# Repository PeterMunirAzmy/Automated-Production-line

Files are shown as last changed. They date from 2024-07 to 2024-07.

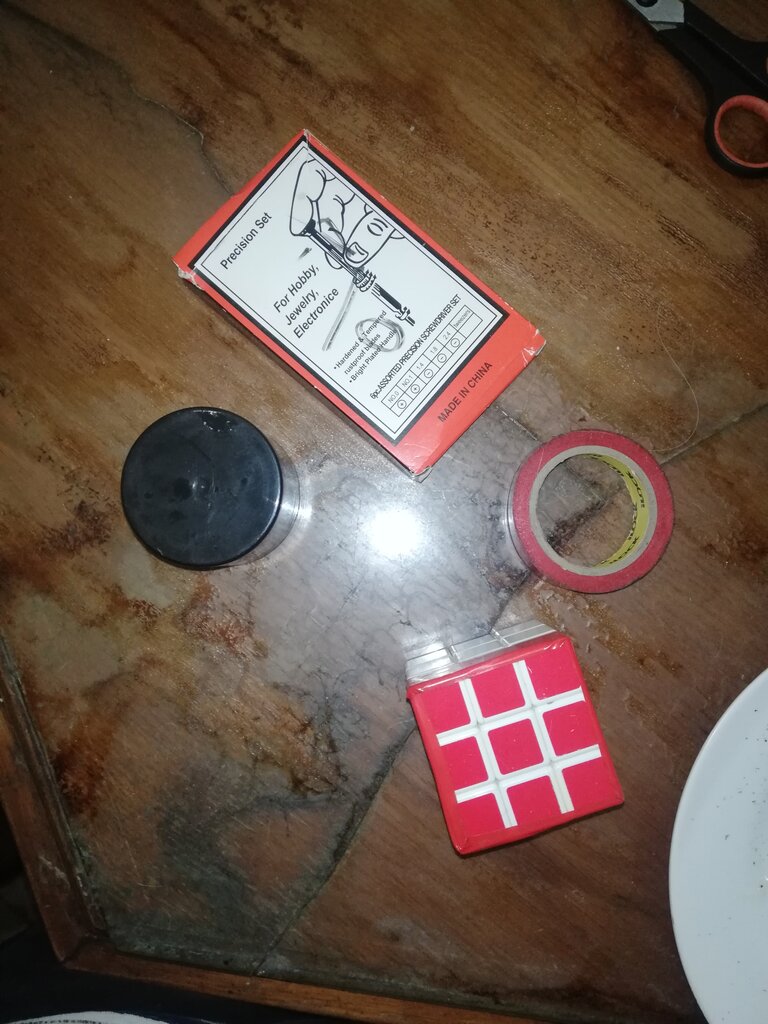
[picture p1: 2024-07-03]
Mechatronics System Desigen/Code/pythonProject/TestImg/objects6 (1).jpg

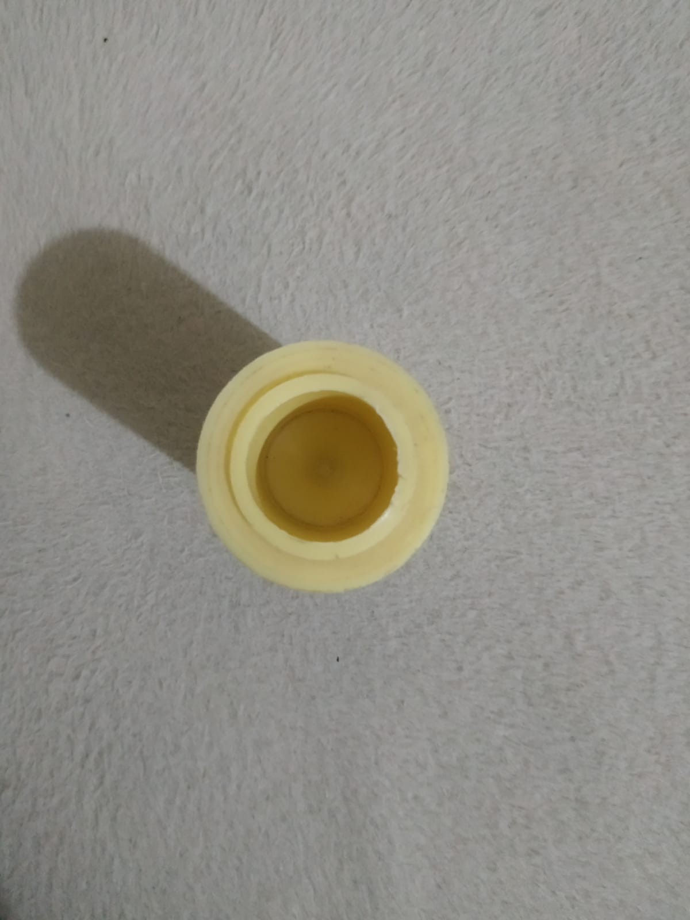
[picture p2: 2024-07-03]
Mechatronics System Desigen/Code/pythonProject/TestImg/circlepeter.jpg

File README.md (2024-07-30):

<h1>Automated Production Line Using Robot Arm</h1>
    <p>This repository contains the files and documentation for a comprehensive automated production line system designed and implemented using a combination of wood, 3D printed parts, NEMA 17 stepper motors, a DC motor, PID control, and CNC V3 shield. The system includes feeding, sorting, handling, assembly, and storage stages, with a vision system for sorting and precise control of a robot arm.</p>

<h2>Table of Contents</h2>
    <ul>
        <li><a href="#overview">Overview</a></li>
        <li><a href="#features">Features</a></li>
        <li><a href="#design-and-fabrication">Design and Fabrication</a></li>
        <li><a href="#control-system">Control System</a></li>
        <li><a href="#vision-system">Vision System</a></li>
        <li><a href="#simulations">Simulations</a></li>
        <li><a href="#hardware-components">Hardware Components</a></li>
        <li><a href="#software">Software</a></li>
        <li><a href="#installation">Installation</a></li>
        <li><a href="#contributing">Contributing</a></li>
    </ul>

<h2 id="overview">Overview</h2>
    <p>The project aims to automate a production line using a robot arm. The system handles multiple stages, including feeding, sorting, handling, assembly, and storage. The design leverages both mechanical and electronic components to ensure precision and reliability.</p>

<h2 id="features">Features</h2>
    <ul>
        <li><strong>Comprehensive Production Line:</strong> Includes stages for feeding, sorting, handling, assembly, and storage.</li>
        <li><strong>Precision Control:</strong> Utilizes NEMA 17 stepper motors and a DC motor with PID control for accurate movement.</li>
        <li><strong>Vision System:</strong> Developed for sorting tasks, ensuring items are correctly categorized.</li>
        <li><strong>Simulations:</strong> MATLAB Simulink used for kinematics and trajectory planning.</li>
        <li><strong>Arduino Control:</strong> Arduino Uno programmed for precise control of the robot arm.</li>
        <li><strong>Modular Design:</strong> Components designed for easy fabrication and assembly.</li>
    </ul>

<h2 id="design-and-fabrication">Design and Fabrication</h2>
    <ul>
        <li><strong>Structural Components:</strong> Fabricated from 4mm thick wood sheets for durability and ease of construction.</li>
        <li><strong>Robot Arm:</strong> 3D printed for precision and durability.</li>
        <li><strong>Software Used:</strong> Autodesk Inventor for design and modeling.</li>
    </ul>

<h2 id="control-system">Control System</h2>
    <ul>
        <li><strong>Motors:</strong> NEMA 17 stepper motors and a DC motor.</li>
        <li><strong>Control:</strong> PID control implemented for precision.</li>
        <li><strong>Coordination:</strong> CNC V3 shield used for seamless motor coordination.</li>
    </ul>

<h2 id="vision-system">Vision System</h2>
    <ul>
        <li><strong>Development:</strong> Custom vision system for sorting items on the production line.</li>
        <li><strong>Integration:</strong> Vision system integrated with the control system for automated sorting.</li>
    </ul>

<h2 id="simulations">Simulations</h2>
    <ul>
        <li><strong>MATLAB Simulink:</strong> Used for simulating kinematics and trajectory planning.</li>
    </ul>

<h2 id="hardware-components">Hardware Components</h2>
    <ul>
        <li><strong>Motors:</strong> NEMA 17 stepper motors, DC motor.</li>
        <li><strong>Microcontroller:</strong> Arduino Uno.</li>
        <li><strong>Shield:</strong> CNC V3 shield.</li>
        <li><strong>Structural:</strong> 4mm thick wood sheets, 3D printed parts.</li>
    </ul>

<h2 id="software">Software</h2>
    <ul>
        <li><strong>Arduino IDE:</strong> For programming the Arduino Uno.</li>
        <li><strong>MATLAB Simulink:</strong> For simulations.</li>
        <li><strong>Autodesk Inventor:</strong> For design and modeling.</li>
    </ul>

<h2 id="installation">Installation</h2>
    <ol>
        <li>Clone the repository:
            <pre><code>git clone https://github.com/yourusername/automated-production-line.git
cd automated-production-line</code></pre>
        </li>
        <li>Install the necessary software:
            <ul>
                <li>MATLAB Simulink</li>
                <li>Autodesk Inventor</li>
                <li>PyCharm</li>
                <li>Arduino IDE</li>
            </ul>
        </li>
        <li>Assemble the hardware components as per the design files provided.</li>
        <li>Upload the Arduino code to the Arduino Uno using the Arduino IDE.</li>
    </ol>

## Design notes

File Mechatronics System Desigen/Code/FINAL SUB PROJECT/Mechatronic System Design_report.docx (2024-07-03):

AIN SHAMS UNIVERSITY

FACULTY OF ENGINEERING

# Mechatronics Engineering

MCT 333s

MS UNIVERSITY

FACULTY OF ENGINEERING

# Mechanical Power Engineering

# MEP221s

MS UNIVERSITY

FACULTY OF ENGINEERING

# Mechanical Power Engineering

# MEP221s

MS UNIVERSITY

FACULTY OF ENGINEERING

# Mechanical Power Engineering

# MEP221s

MS UNIVERSITY

FACULTY OF ENGINEERING

# Mechanical Power Engineering

# MEP221s

MS UNIVERSITY

FACULTY OF ENGINEERING

# Mechanical Power Engineering

# MEP221s

MS UNIVERSITY

FACULTY OF ENGINEERING

# Mechanical Power Engineering

# MEP221s

MS UNIVERSITY

FACULTY OF ENGINEERING

# Mechanical Power Engineering

# MEP221s

MS UNIVERSITY

FACULTY OF ENGINEERING

# Mechatronics Engineering

# MEP221s

MS UNIVERSITY

FACULTY OF ENGINEERING

# Mechanical Power Engineering

# MEP221s

MS UNIVERSITY

FACULTY OF ENGINEERING

# Mechanical Power Engineering

# MEP221s

MS UNIVERSITY

FACULTY OF ENGINEERING

# Mechanical Power Engineering

# MEP221s

MS UNIVERSITY

FACULTY OF ENGINEERING

# Mechanical Power Engineering

# MEP221s

MS UNIVERSITY

FACULTY OF ENGINEERING

# Mechanical Power Engineering

# MEP221s

MS UNIVERSITY

FACULTY OF ENGINEERING

# Mechanical Power Engineering

# MEP221s

MS UNIVERSITY

FACULTY OF ENGINEERING

# Mechanical Power Engineering

# MEP221s

Mechatronic System Design

(MCT 333s)

Production line project

NAME LIST:

Team (20)

NO | B. N | NAME | ID | sec
1 | | Peter Munir Azmy | 1901934 | 2
2 | | Fares Ahmed Mohamed | 19P6135 | 2
3 | | Hassan Ahmed Mohamden | 2002008 | 2
4 | | Ahmed Hawary Abdelrehem ali | 2000135 | 2
5 | | Mahmoud Mohamed Ibrahim Ali | 2001481 | 3
6 | | Mohamed Hany Farouk | 2001266 | 3

- Introduction:

A production line, also known as an assembly line, is a manufacturing process in which parts are added to a product in a sequential manner to create a finished product more efficiently. This method is used in mass production and involves a series of workstations that perform different tasks simultaneously, but at a controlled pace. The key advantages of a production line include increased productivity, more efficient use of materials, improved product quality, and faster production times. This system was popularized by Henry Ford in the early 20th century, revolutionizing the automotive industry by making the assembly process quicker and more cost-effective. Today, production lines are integral to various industries, including electronics, food, and pharmaceuticals, adapting to new technologies such as automation and robotics to enhance efficiency and precision.

- machine vision with production line _robotic arm:

A robotic arm with machine vision on a production line represents the pinnacle of technological integration in industrial automation, blending precision mechanics with sophisticated image processing capabilities. These robotic arms are equipped with cameras and sensors that allow them to "see" their environment. This ability to visually analyze their surroundings enables them to perform complex tasks such as quality control inspections, precise assembly, and intricate component handling with higher accuracy and adaptability.

Machine vision systems enable robotic arms to identify, sort, and position parts with a level of precision that far surpasses human capabilities. These systems use real-time data to guide the robot's actions, allowing for adjustments on the fly and enabling the handling of a diverse range of products without manual reprogramming. This integration significantly enhances the flexibility and efficiency of production lines, particularly in industries where customization and high-quality standards are critical, such as in electronics manufacturing, pharmaceuticals, and automotive assembly.

The use of machine vision in robotic arms not only boosts production throughput and product quality but also reduces waste and operational costs by minimizing errors and improving safety. As part of smart manufacturing practices, these technologically advanced robotic systems play a crucial role in the ongoing evolution of Industry 4.0, pushing the boundaries of what automated production lines can achieve.

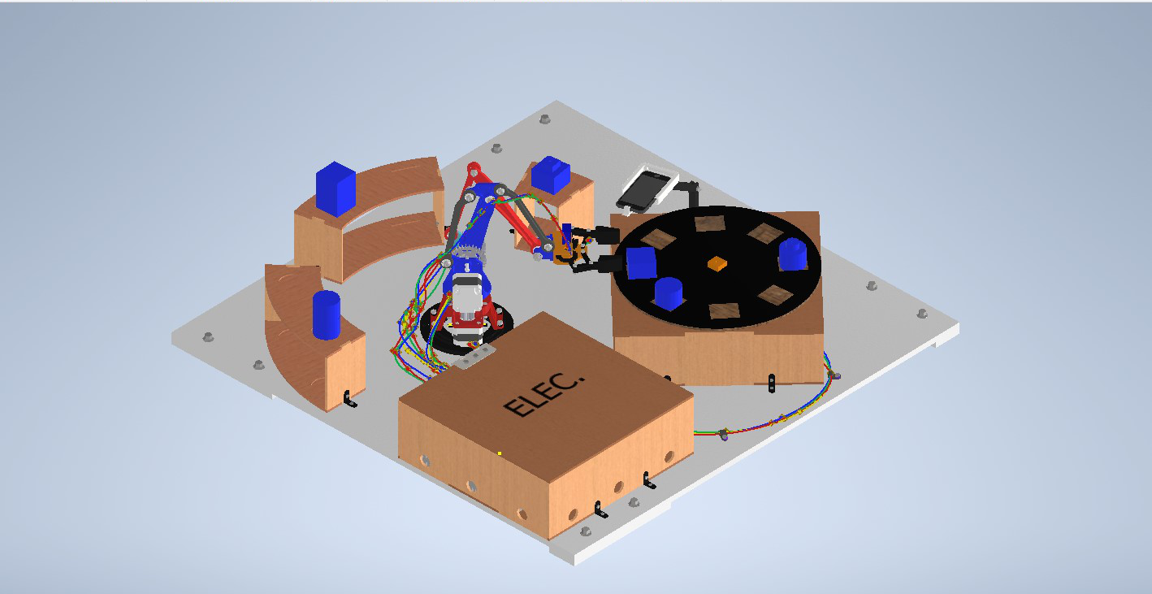
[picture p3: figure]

Machine vision camera

Square surface detection

- V_model techniques for project:

In this project, we are constrained by 5 main stages, but we can make any design to achieve these stages, we design a simple design with main robot arm to make most of it.

- We select our requirements based on 5 stages:

Stage | Function | Requirement
1-Feeding | Feeding the products to certain position to pick up by the robot | We make a feeding mechanism by rotating disk rotated by DC motor controlled by PID controller
2-Sorting | Sorting the products based on shapes (circle _square) by edge detection | we need to use machine vision (via camera)
3-handling | we need to handle the products from place to place and assembly the similar products which other and storge it | We need to a robotic arm can make this function with 3 DOF or more with end effector
4-assembly
5-storg

- Mechanical design and modeling:

We divided the production line that makes five stages for a product to 2 stations:

1- Station includes (Feeding _ sorting)
2- Station includes (handling _assembly _storage)
- Station includes (Feeding _ sorting):
- Mechanical design:

The design of the feeding mechanism depends on the presence of a disk that rotates with the help of a DC motor with a PID controller to adjust the circular angles divided into every 45 degrees (in the form of square shape ), from which the robot picks up the product after classifying it with the camera that knows if the type of product is Where if it is circular or square in shape.

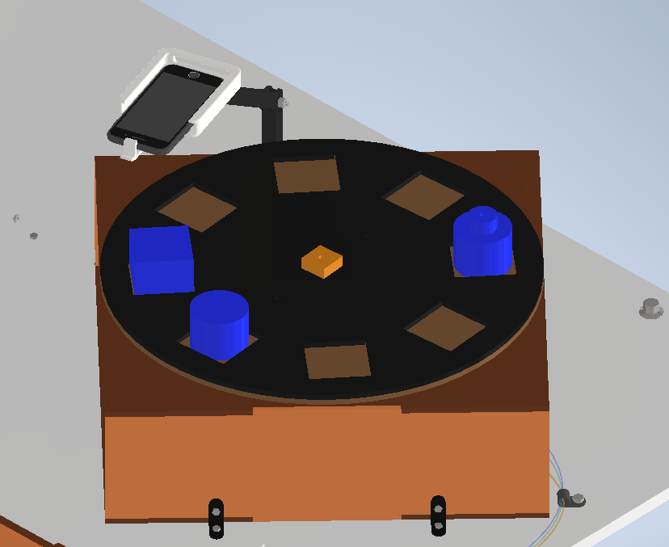
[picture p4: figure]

Image from cad file for feeding and sorting.

The used motor for feeding mechanism:

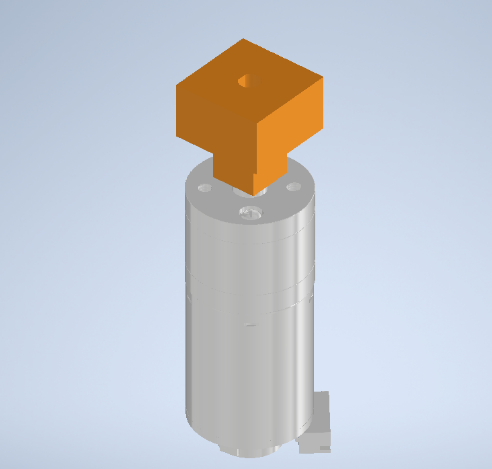
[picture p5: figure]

DC Motors 25GA-370 Metal Gear DC 12V Reduction Motor with Encoder and Gearbox for 280RPM With use with motor a 3d coupler to link between motor and rotating disk.

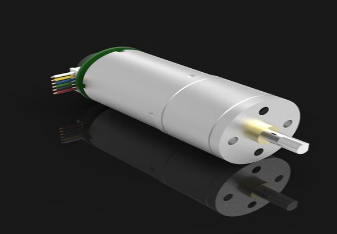
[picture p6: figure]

Dc motor

3D printed coupler

dc motor with coupler

The used camera is:

We use a mobile camera (mi note 10) connected with laptop by program (Iriun Webcam) with stand from our design to hold it.

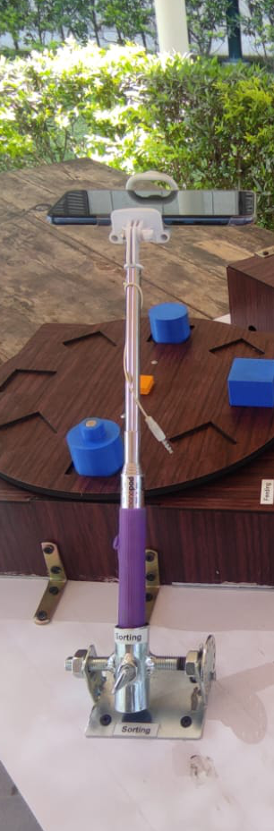
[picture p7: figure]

We use a thrust bearing (51105) between the rotating disk and the fixed surface to reduce the friction force.

- Modeling and simulation:

by using MATLAB Simulink to model the system

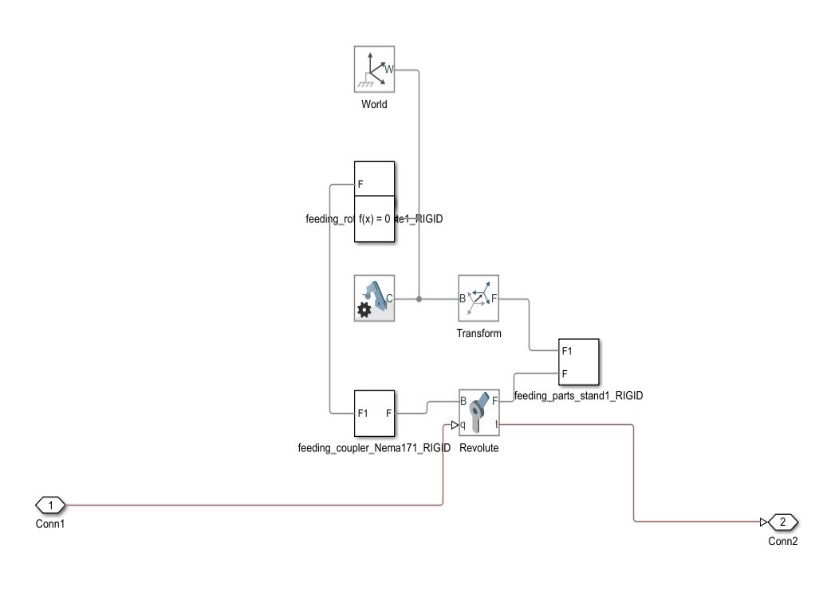
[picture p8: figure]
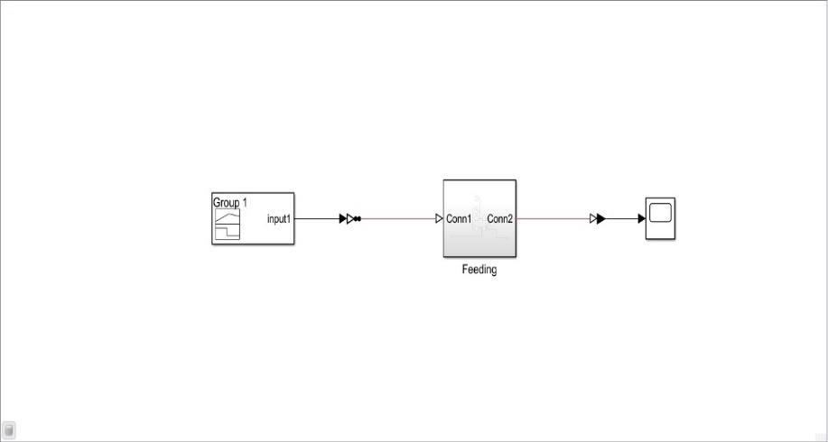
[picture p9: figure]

Feeding model in MATLAB

From the results we select the motor which achieves this torque and actuate the mechanism and the is DC Motors 25GA-370 Metal Gear DC 12V Reduction Motor with Encoder and Gearbox for 280RPM with Stall Torque: 3Kg/cm.

Link of cad files:

- Station includes (handling _assembly _storage):
- Mechanical design:

In these 3 stages, the robot picks up the product, then assembles it with a similar part, then storges it in a desired place for that.

This 3DOF_ robot is made by Florin Tobler _2016 and we make an inverse engineering to it to be suitable at this case and can matching with Egyptian industry conditions and the presence of components in the markets.

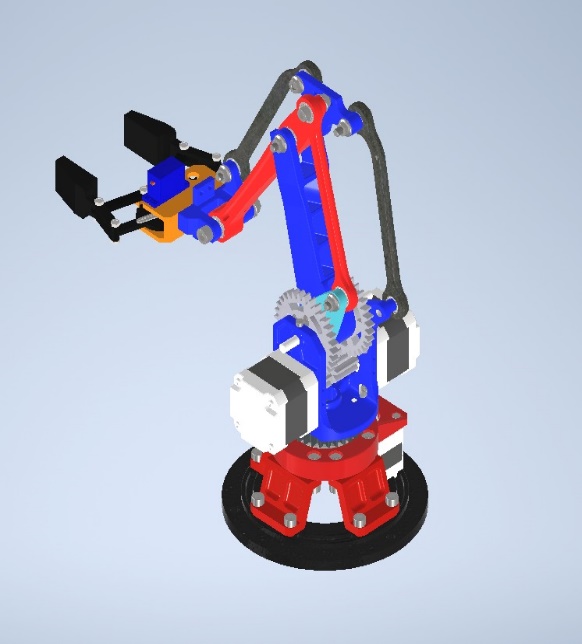
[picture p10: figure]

Robotic arm from cad file

For the robotic arm we use inverse engineering techniques to check everything at the robot:

1- length of links and its ability to achieve the function.
2- considering the friction between joints by using a lot of types from bearing (deep grove ball bearing (686zz) – thrust bearing (51105)).

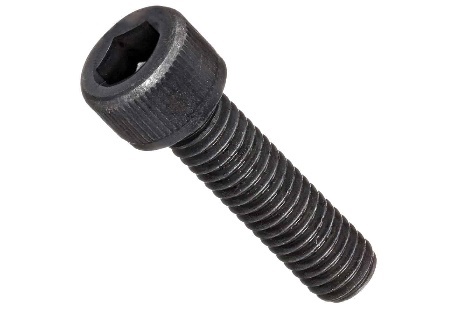
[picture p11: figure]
Socket Head Cap Screws - Metric - DIN 912 | TFC Ltd
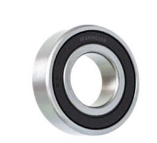
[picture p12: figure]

3- the loads in each part and the selection motor by modeling it MATLAB.
4- Considering The techniques of fabrication on The Egyptian environment and Availability of screws, nuts, and fixing tools.

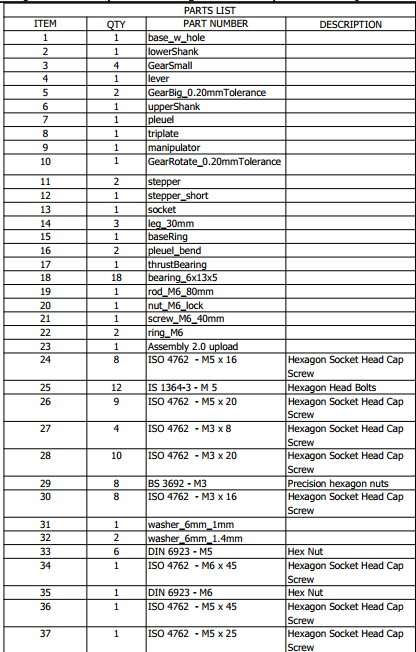
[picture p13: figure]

the BOM to robot arm:

5- Considering The size and the loads of the gripper and an ability to hold the parts.
- Modeling and simulation:

by using MATLAB Simulink to model the system

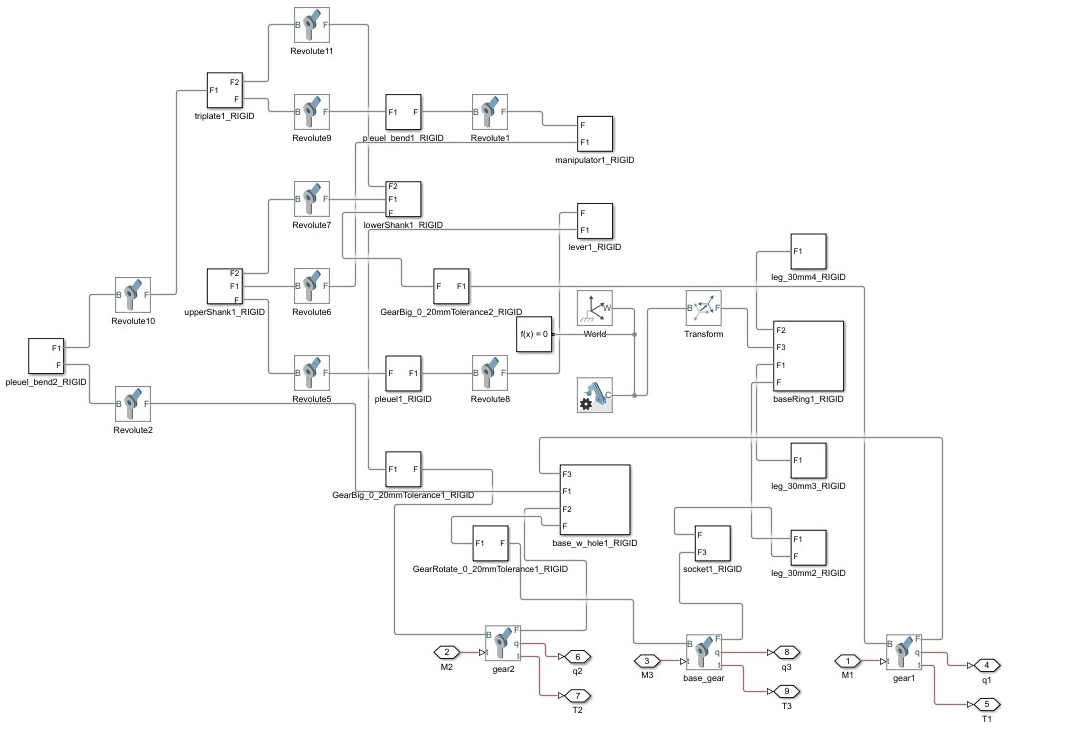
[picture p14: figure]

Cad file robot in Simulink

-Actuator sizing:

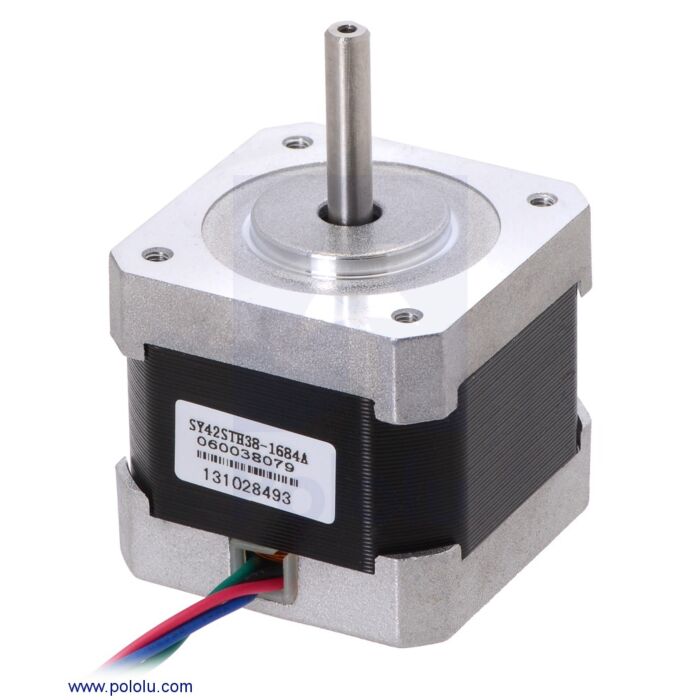
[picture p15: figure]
Stepper Motor: Bipolar, 200 Steps/Rev, 42×38mm, 2.8V, 1.7 A/Phase | POLOLU-2267 | Core Electronics Australia

From the results we select the motor which achieves this torque and actuate the mechanism and the is This robot will be actuator by stepper motor _Nema 17_to achieving arrival for certain angle.

We use 3 motors to actuate 3 angles in a robot arm.

-Inverse kinematics:

Inverse kinematics allows precise control over the motion of the end effector by calculating the required joint configurations to achieve a desired position and orientation in the workspace.

For robotic arms with multiple joints, determining the joint angles manually to reach a specific end effector position.

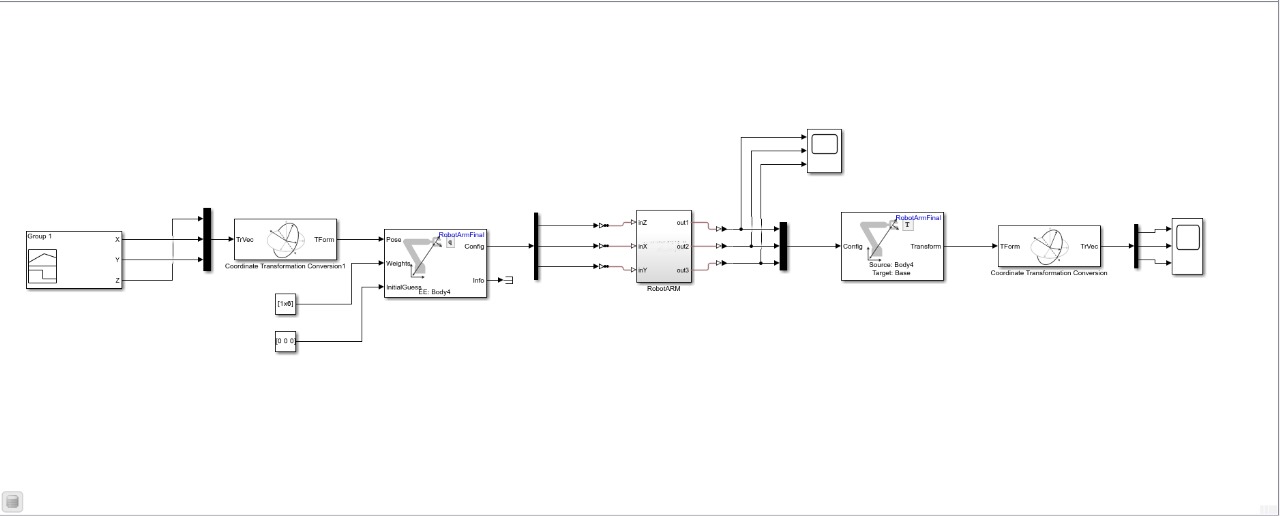
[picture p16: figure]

-Forward kinematics:

in robot kinematics, forward kinematics refers to the use of the kinematic equations of a robot to compute the position of the end-effector from specified values for the joint parameters.

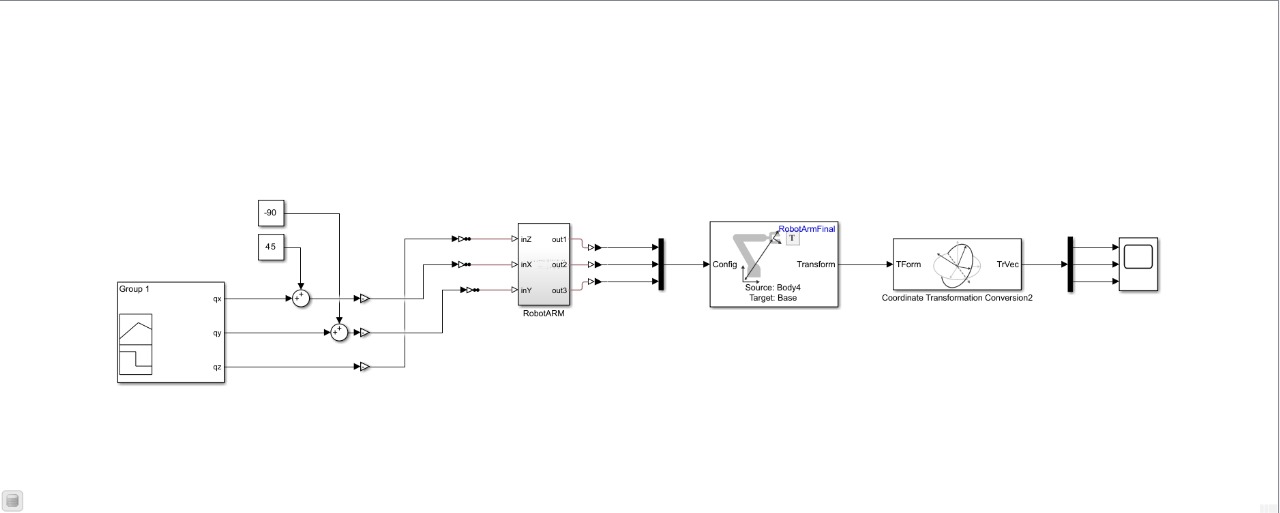
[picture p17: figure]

- trajectory planning:

robot manipulator trajectory planning takes the ideal trajectory kinematics parameters and the robot manipulator system as the input, and takes the displacement, velocity and acceleration of each joint and end effector as the output.

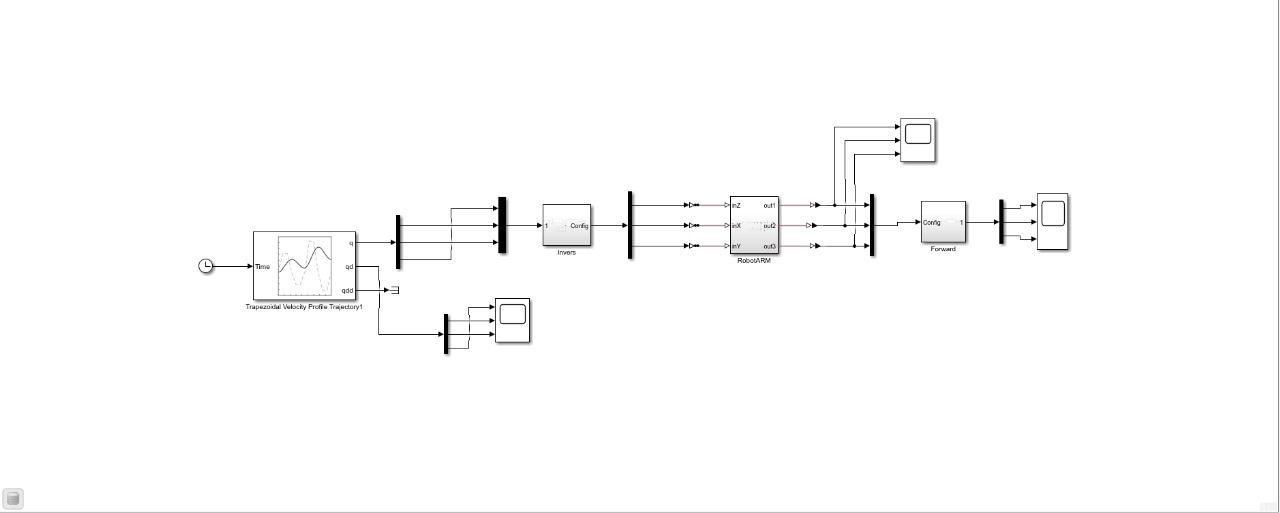
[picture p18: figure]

-Jacobian matrix:

Jacobian is the determinant of the Jacobian matrix. The matrix will contain all partial derivatives of a vector function. The main use of Jacobian is found in the transformation of coordinates. It deals with the concept of differentiation with coordinate transformation.

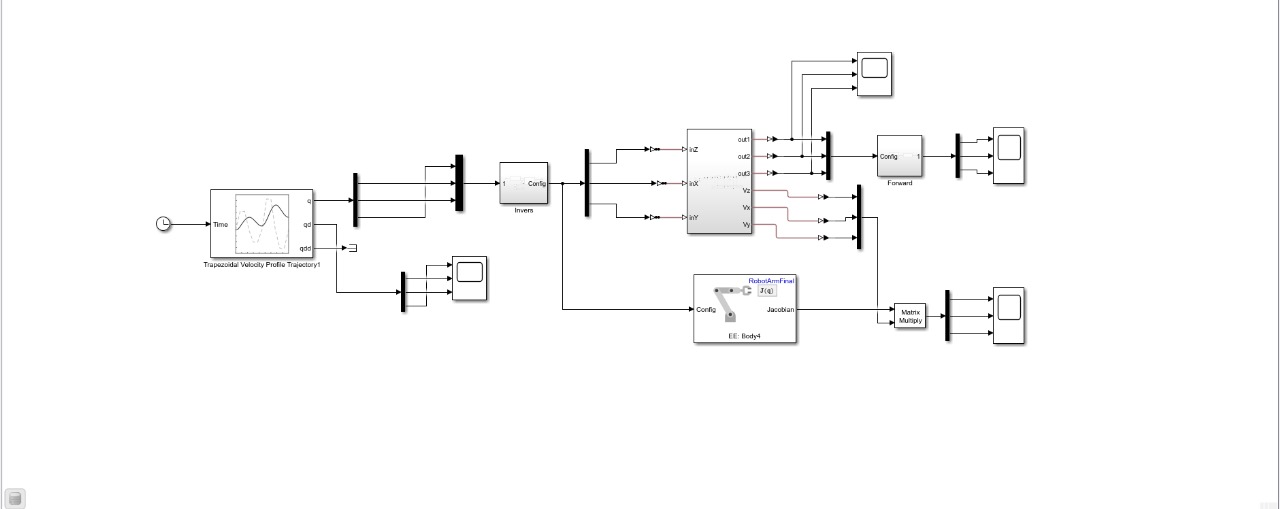
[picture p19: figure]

- The fabrication processes:

We use wooden laser cut to build the feeding mechanism and the stand which the robot will put the products in it.

And use the 3d printer to abdicate the robot arm.

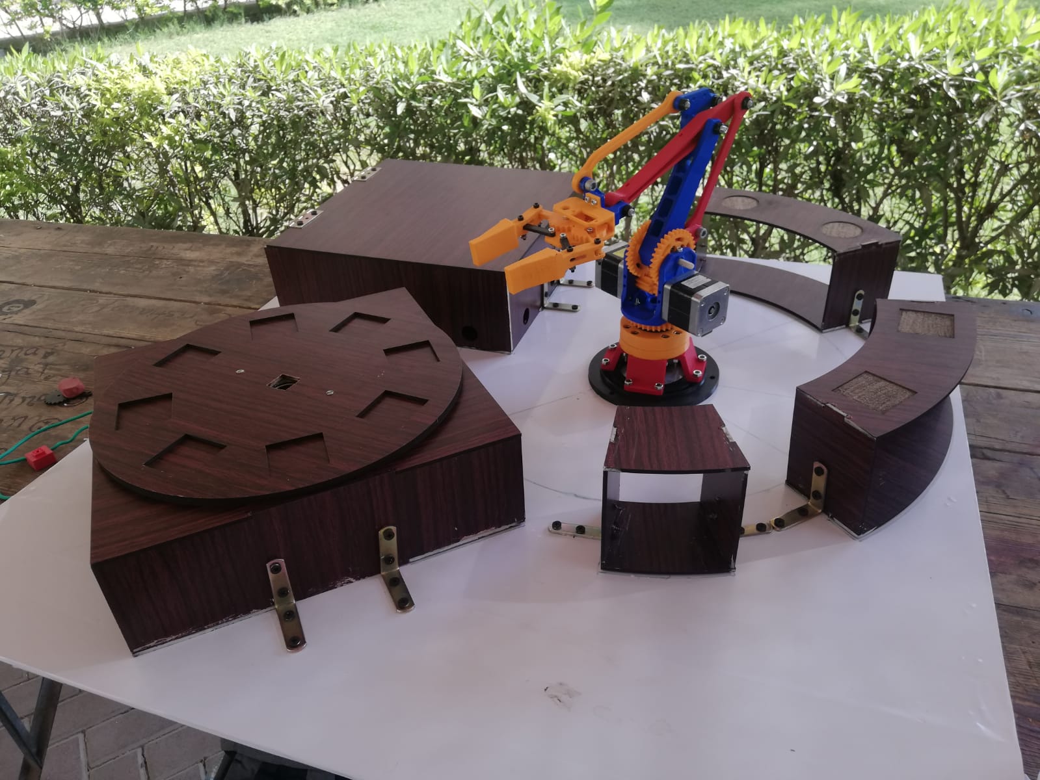
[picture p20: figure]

- The electrical system and integration:
- The sequence of the project and algorithms

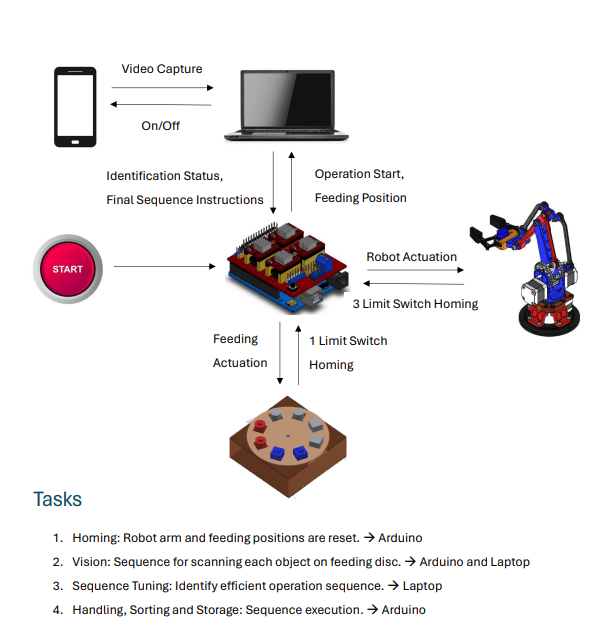
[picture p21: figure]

- Summary:

As soon as we connect the power, the robot performs a homing and returns to the initial position. After that, the feeding mechanism performs a homing and returns to the initial position. After that, the laptop takes pictures of each part separately to move to the next time once the products are captured correctly and the word “Done” is displayed, then after. The laptop then gives a sequence of the location of each product, so the robot collects similar products on this basis, assembles them, and then transports them to their storage location.

We use two microprocessors (Arduino uno - laptop) , the two microprocessors connecting with to each other with UART protocol via USB.

- Flow chart:

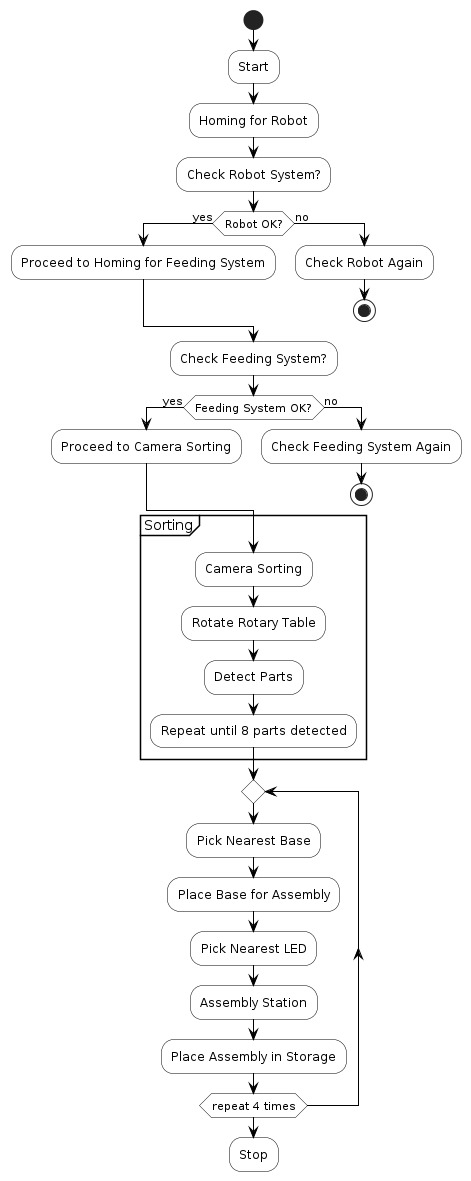
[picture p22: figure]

- the schematic electrical circuit:

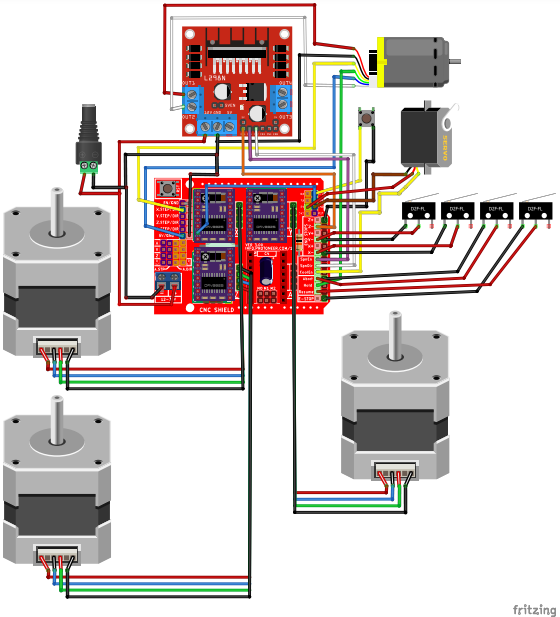
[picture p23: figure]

- The PID controller on DC motor in feeding:

We Utilize sensors like encoders to measure the motor's current position, providing feedback for the control system.

1. Proportional (P) Control: Adjust motor speed based on the difference between desired and current position, increasing or decreasing power accordingly to move closer to the setpoint.

2. Integral (I) Control: Accumulate errors over time to eliminate steady-state error, correcting for any system bias preventing the motor from reaching the desired position.

4. Derivative (D) Control: Anticipate changes in error rate to dampen overshoot and oscillations, adjusting power based on the rate of change of error.

5. Tuning Parameters: Crucially adjust PID parameters to balance responsiveness, stability, and accuracy, typically starting with proportional gain and incrementally adding integral and derivative terms while observing system response.

6. Continuous Adjustment: Once tuned, the PID controller continuously computes a control signal based on the error, ensuring the motor reaches and maintains the desired position accurately and efficiently.

In essence, PID control offers a versatile and effective method for precise position control of DC motors, crucial for various applications like robotics and automation systems.

In our case We chose it due to previous experiences with PID values for same motor and modified it with our case.

| Kp | Ki | Kd
Value | 5.2 | 0.001 | 1.0

Pode blot between desired and set point:

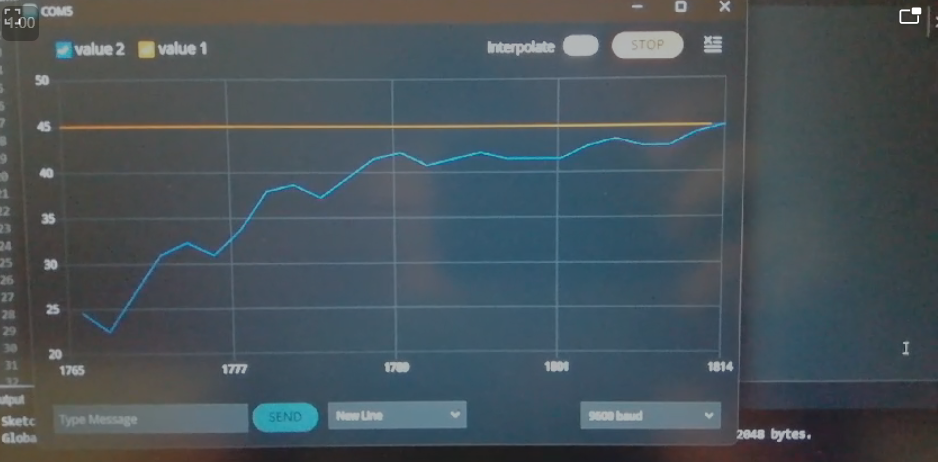
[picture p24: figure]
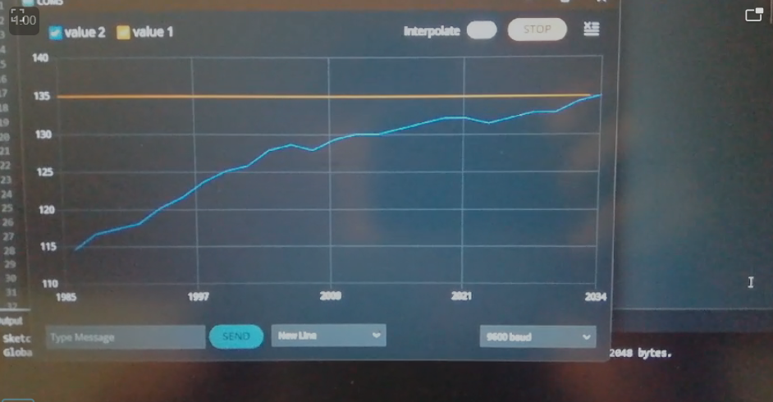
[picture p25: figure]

- The final product and problems faced:

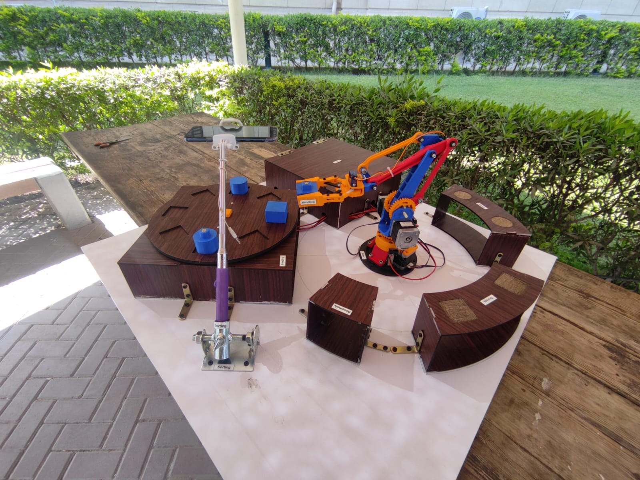
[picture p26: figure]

Final product

- problems faced:
1- the small error on PID controller and This causes the product not to be caught by the robot.

We made a great effort to avoid this error by controlling and changing PID parameters, but we were not able to remove it due to the poor quality of the motor.

2- The machine vision camera is affected by external factors such as light, so it must be adjusted before conducting the experiment.
3- The problems of MATLAB program as error, we can’t solve it.
4- The gripper when its puck up the products, we solve it by change motor with high torque to overcome the friction between links and bolts and nuts.
5- Modifying the CNC shield to can use one Arduino, That modification is to remove the Step-X motor pin 2 and connect it to the pin 0, so that we can use the pin 2 with interrupt with DC encoders.

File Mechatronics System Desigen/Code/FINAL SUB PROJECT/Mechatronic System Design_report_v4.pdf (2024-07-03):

1 | P a g e


### AIN SHAMS UNIVERSITY FACULTY OF ENGINEERING Mechatronics Engineering MCT 333s

# Mechatronic System Design (MCT 333s)

# Production line project

NAME LIST:

## Team (20)

NO | B. N | NAME | ID | sec
1 | | Peter Munir Azmy | 1901934 | 2
2 | | Fares Ahmed Mohamed | 19P6135 | 2
3 | | Hassan Ahmed Mohamden | 2002008 | 2
4 Ahmed Hawary Abdelrehem | | ali | 2000135 | 2
5 Mahmoud Mohamed Ibrahim | | Ali | 2001481 | 3
6 | | Mohamed Hany Farouk | 2001266 | 3

2 | P a g e

## - Introduction:

A production line, also known as an assembly line, is a manufacturing process in which parts are added to a product in a sequential manner to create a finished product more efficiently. This method is used in mass production and involves a series of workstations that perform different tasks simultaneously, but at a controlled pace. The key advantages of a production line include increased productivity, more efficient use of materials, improved product quality, and faster production times. This system was popularized by Henry Ford in the early 20th century, revolutionizing the automotive industry by making the assembly process quicker and more cost-effective. Today, production lines are integral to various industries, including electronics, food, and pharmaceuticals, adapting to new technologies such as automation and robotics to enhance efficiency and precision.

- machine vision with production line _robotic arm:

A robotic arm with machine vision on a production line represents the pinnacle of technological integration in industrial automation, blending precision mechanics with sophisticated image processing capabilities. These robotic arms are equipped with cameras and sensors that allow them to "see" their environment. This ability to visually analyze their surroundings enables them to perform complex tasks such as quality control inspections, precise assembly, and intricate component handling with higher accuracy and adaptability.

Machine vision systems enable robotic arms to identify, sort, and position parts with a level of precision that far surpasses human capabilities. These systems use real-time data to guide the robot's actions, allowing for adjustments on the fly and enabling the handling of a diverse range of products without manual reprogramming. This integration significantly enhances the flexibility and efficiency of production lines, particularly in industries where customization and high-quality standards are critical, such as in electronics manufacturing, pharmaceuticals, and automotive assembly.

The use of machine vision in robotic arms not only boosts production throughput and product quality but also reduces waste and operational costs


3 | P a g e

by minimizing errors and improving safety. As part of smart manufacturing practices, these technologically advanced robotic systems play a crucial role in the ongoing evolution of Industry 4.0, pushing the boundaries of what automated production lines can achieve.

Machine vision camera Square surface detection

4 | P a g e

## - V_model techniques for project:

In this project, we are constrained by 5 main stages, but we can make any design to achieve these stages, we design a simple design with main robot arm to make most of it.

- We select our requirements based on 5 stages:
Stage | Function | Requirement
1-Feeding | Feeding the products to certain position to pick up by the robot | We make a feeding mechanism by rotating disk rotated by DC motor controlled by PID controller
2-Sorting | Sorting the products based on shapes (circle _square) by edge detection | we need to use machine vision (via camera)
3-handling | we need to handle the products from place to place and assembly the similar products which other and storge it | We need to a robotic arm can make this function with 3 DOF or more with end effector

4-assembly

5-storg


5 | P a g e
- Mechanical design and modeling:

We divided the production line that makes five stages for a product to 2 stations:
1- Station includes (Feeding _ sorting)
2- Station includes (handling _assembly _storage)
- Station includes (Feeding _ sorting):
- Mechanical design:
The design of the feeding mechanism depends on the presence of a disk that rotates with the help of a DC motor with a PID controller to adjust the circular angles divided into every 45 degrees (in the form of square shape ), from which the robot picks up the product after classifying it with the camera that knows if the type of product is Where if it is circular or square in shape.

Image from cad file for feeding and sorting.


6 | P a g e

The used motor for feeding mechanism:

DC Motors 25GA-370 Metal Gear DC 12V Reduction Motor with Encoder and Gearbox for 280RPM With use with motor a 3d coupler to link between motor and rotating disk.

The used camera is:


We use a mobile camera (mi note 10) connected with laptop by program (Iriun Webcam) with stand from our design to hold it.

Dc motor | 3D printed coupler
dc motor with coupler


7 | P a g e

We use a thrust bearing (51105) between the rotating disk and the fixed surface to reduce the friction force.


- Modeling and simulation:
by using MATLAB Simulink to model the system


Feeding model in MATLAB

8 | P a g e

From the results we select the motor which achieves this torque and actuate the mechanism and the is DC Motors 25GA-370 Metal Gear DC 12V Reduction Motor with Encoder and Gearbox for 280RPM with Stall Torque: 3Kg/cm.

Link of cad files:

- Station includes (handling _assembly _storage):
- Mechanical design:

In these 3 stages, the robot picks up the product, then assembles it with a similar part, then storges it in a desired place for that.

This 3DOF_ robot is made by Florin Tobler _2016 and we make an inverse engineering to it to be suitable at this case and can matching with Egyptian industry conditions and the presence of components in the markets.


Robotic arm from cad file


9 | P a g e

For the robotic arm we use inverse engineering techniques to check everything at the robot:
1- length of links and its ability to achieve the function.
2- considering the friction between joints by using a lot of types from bearing (deep grove ball bearing (686zz) – thrust bearing (51105)).

3- the loads in each part and the selection motor by modeling it MATLAB. 4- Considering The techniques of fabrication on The Egyptian environment and Availability of screws, nuts, and fixing tools.
the BOM to robot arm:


10 | P a g e

5- Considering The size and the loads of the gripper and an ability to hold the parts.

- Modeling and simulation:
by using MATLAB Simulink to model the system

Cad file robot in Simulink


11 | P a g e

-Actuator sizing:
From the results we select the motor which achieves this torque and actuate the mechanism and the is This
robot will be actuator by stepper motor _Nema 17_to achieving arrival for certain angle.

We use 3 motors to actuate 3 angles in a robot arm.

-Inverse kinematics:


Inverse kinematics allows precise control over the motion of the end

effector by calculating the required joint configurations to achieve a desired

position and orientation in the workspace.

For robotic arms with multiple joints, determining the joint angles manually

to reach a specific end effector position.


12 | P a g e

-Forward kinematics:

in robot kinematics, forward kinematics refers to the use of the kinematic equations of a robot to compute the position of the end-effector from specified values for the joint parameters.

- trajectory planning:

robot manipulator trajectory planning takes the ideal trajectory kinematics parameters and the

robot manipulator system as the input, and takes the displacement, velocity and acceleration of

each joint and end effector as the output.


13 | P a g e

-Jacobian matrix:

Jacobian is the determinant of the Jacobian matrix. The matrix will contain all partial derivatives of a vector function. The main use of Jacobian is found in the transformation of coordinates. It deals with the concept of differentiation with coordinate transformation.


14 | P a g e
- The fabrication processes:

We use wooden laser cut to build the feeding mechanism and the stand which the robot will put the products in it.

And use the 3d printer to abdicate the robot arm.


15 | P a g e
- The electrical system and integration:
- The sequence of the project and algorithms

16 | P a g e
- Summary:

As soon as we connect the power, the robot performs a homing

and returns to the initial position. After that, the feeding

mechanism performs a homing and returns to the initial position.

After that, the laptop takes pictures of each part separately to

move to the next time once the products are captured correctly

and the word “Done” is displayed, then after. The laptop then

gives a sequence of the location of each product, so the robot

collects similar products on this basis, assembles them, and then

transports them to their storage location.

We use two microprocessors (Arduino uno - laptop) , the two

microprocessors connecting with to each other with UART

protocol via USB.


17 | P a g e
- Flow chart:


18 | P a g e
- the schematic electrical circuit:

19 | P a g e
- The PID controller on DC motor in feeding:

We Utilize sensors like encoders to measure the motor's current position, providing feedback for the control system.

1. Proportional (P) Control: Adjust motor speed based on the difference between desired and current position, increasing or decreasing power accordingly to move closer to the setpoint.
2. Integral (I) Control: Accumulate errors over time to eliminate steady-state error, correcting for any system bias preventing the motor from reaching the desired position.
4. Derivative (D) Control: Anticipate changes in error rate to dampen overshoot and oscillations, adjusting power based on the rate of change of error.
5. Tuning Parameters: Crucially adjust PID parameters to balance responsiveness, stability, and accuracy, typically starting with proportional gain and incrementally adding integral and derivative terms while observing system response.
6. Continuous Adjustment: Once tuned, the PID controller continuously computes a control signal based on the error, ensuring the motor reaches and maintains the desired position accurately and efficiently.

In essence, PID control offers a versatile and effective method for precise position control of DC motors, crucial for various applications like robotics and automation systems.
In our case We chose it due to previous experiences with PID values for same motor and modified it with our case.
| Kp | Ki | Kd
Value | 5.2 | 0.001 | 1.0


20 | P a g e

Pode blot between desired and set point:

➢ The final product and problems faced:; • problems faced:; caught by the robot.; quality of the motor.; Final product

1- | the small error on PID controller and This causes the product not to be
| We made a great effort to avoid this error by controlling and changing PID parameters, but we were not able to remove it due to the poor

22 | P a g e
2- | The machine vision camera is affected by external factors such as light, so it must be adjusted before conducting the experiment.
3- | The problems of MATLAB program as error, we can’t solve it.
4- | The gripper when its puck up the products, we solve it by change motor with high torque to overcome the friction between links and bolts and nuts.
5- | Modifying the CNC shield to can use one Arduino, That modification is to remove the Step-X motor pin 2 and connect it to the pin 0, so that we can use the pin 2 with interrupt with DC encoders.

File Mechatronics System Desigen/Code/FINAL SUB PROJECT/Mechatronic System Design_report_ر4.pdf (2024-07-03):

1 | P a g e


### AIN SHAMS UNIVERSITY FACULTY OF ENGINEERING Mechatronics Engineering MCT 333s

# Mechatronic System Design (MCT 333s)

# Production line project

NAME LIST:

## Team (20)

NO | B. N | NAME | ID | sec
1 | | Peter Munir Azmy | 1901934 | 2
2 | | Fares Ahmed Mohamed | 19P6135 | 2
3 | | Hassan Ahmed Mohamden | 2002008 | 2
4 Ahmed Hawary Abdelrehem | | ali | 2000135 | 2
5 Mahmoud Mohamed Ibrahim | | Ali | 2001481 | 3
6 | | Mohamed Hany Farouk | 2001266 | 3

2 | P a g e

## - Introduction:

A production line, also known as an assembly line, is a manufacturing process in which parts are added to a product in a sequential manner to create a finished product more efficiently. This method is used in mass production and involves a series of workstations that perform different tasks simultaneously, but at a controlled pace. The key advantages of a production line include increased productivity, more efficient use of materials, improved product quality, and faster production times. This system was popularized by Henry Ford in the early 20th century, revolutionizing the automotive industry by making the assembly process quicker and more cost-effective. Today, production lines are integral to various industries, including electronics, food, and pharmaceuticals, adapting to new technologies such as automation and robotics to enhance efficiency and precision.

- machine vision with production line _robotic arm:

A robotic arm with machine vision on a production line represents the pinnacle of technological integration in industrial automation, blending precision mechanics with sophisticated image processing capabilities. These robotic arms are equipped with cameras and sensors that allow them to "see" their environment. This ability to visually analyze their surroundings enables them to perform complex tasks such as quality control inspections, precise assembly, and intricate component handling with higher accuracy and adaptability.

Machine vision systems enable robotic arms to identify, sort, and position parts with a level of precision that far surpasses human capabilities. These systems use real-time data to guide the robot's actions, allowing for adjustments on the fly and enabling the handling of a diverse range of products without manual reprogramming. This integration significantly enhances the flexibility and efficiency of production lines, particularly in industries where customization and high-quality standards are critical, such as in electronics manufacturing, pharmaceuticals, and automotive assembly.

The use of machine vision in robotic arms not only boosts production throughput and product quality but also reduces waste and operational costs


3 | P a g e

by minimizing errors and improving safety. As part of smart manufacturing practices, these technologically advanced robotic systems play a crucial role in the ongoing evolution of Industry 4.0, pushing the boundaries of what automated production lines can achieve.

Machine vision camera Square surface detection

4 | P a g e

## - V_model techniques for project:

In this project, we are constrained by 5 main stages, but we can make any design to achieve these stages, we design a simple design with main robot arm to make most of it.

- We select our requirements based on 5 stages:
Stage | Function | Requirement
1-Feeding | Feeding the products to certain position to pick up by the robot | We make a feeding mechanism by rotating disk rotated by DC motor controlled by PID controller
2-Sorting | Sorting the products based on shapes (circle _square) by edge detection | we need to use machine vision (via camera)
3-handling | we need to handle the products from place to place and assembly the similar products which other and storge it | We need to a robotic arm can make this function with 3 DOF or more with end effector

4-assembly

5-storg


5 | P a g e
- Mechanical design and modeling:

We divided the production line that makes five stages for a product to 2 stations:
1- Station includes (Feeding _ sorting)
2- Station includes (handling _assembly _storage)
- Station includes (Feeding _ sorting):
- Mechanical design:
The design of the feeding mechanism depends on the presence of a disk that rotates with the help of a DC motor with a PID controller to adjust the circular angles divided into every 45 degrees (in the form of square shape ), from which the robot picks up the product after classifying it with the camera that knows if the type of product is Where if it is circular or square in shape.

Image from cad file for feeding and sorting.


6 | P a g e

The used motor for feeding mechanism:

DC Motors 25GA-370 Metal Gear DC 12V Reduction Motor with Encoder and Gearbox for 280RPM With use with motor a 3d coupler to link between motor and rotating disk.

The used camera is:


We use a mobile camera (mi note 10) connected with laptop by program (Iriun Webcam) with stand from our design to hold it.

Dc motor | 3D printed coupler
dc motor with coupler


7 | P a g e

We use a thrust bearing (51105) between the rotating disk and the fixed surface to reduce the friction force.


- Modeling and simulation:
by using MATLAB Simulink to model the system


Feeding model in MATLAB

8 | P a g e

From the results we select the motor which achieves this torque and actuate the mechanism and the is DC Motors 25GA-370 Metal Gear DC 12V Reduction Motor with Encoder and Gearbox for 280RPM with Stall Torque: 3Kg/cm.

Link of cad files:

- Station includes (handling _assembly _storage):
- Mechanical design:

In these 3 stages, the robot picks up the product, then assembles it with a similar part, then storges it in a desired place for that.

This 3DOF_ robot is made by Florin Tobler _2016 and we make an inverse engineering to it to be suitable at this case and can matching with Egyptian industry conditions and the presence of components in the markets.


Robotic arm from cad file


9 | P a g e

For the robotic arm we use inverse engineering techniques to check everything at the robot:
1- length of links and its ability to achieve the function.
2- considering the friction between joints by using a lot of types from bearing (deep grove ball bearing (686zz) – thrust bearing (51105)).

3- the loads in each part and the selection motor by modeling it MATLAB. 4- Considering The techniques of fabrication on The Egyptian environment and Availability of screws, nuts, and fixing tools.
the BOM to robot arm:


10 | P a g e

5- Considering The size and the loads of the gripper and an ability to hold the parts.

- Modeling and simulation:
by using MATLAB Simulink to model the system

Cad file robot in Simulink


11 | P a g e

-Actuator sizing:
From the results we select the motor which achieves this torque and actuate the mechanism and the is This
robot will be actuator by stepper motor _Nema 17_to achieving arrival for certain angle.

We use 3 motors to actuate 3 angles in a robot arm.

-Inverse kinematics:


Inverse kinematics allows precise control over the motion of the end

effector by calculating the required joint configurations to achieve a desired

position and orientation in the workspace.

For robotic arms with multiple joints, determining the joint angles manually

to reach a specific end effector position.


12 | P a g e

-Forward kinematics:

in robot kinematics, forward kinematics refers to the use of the kinematic equations of a robot to compute the position of the end-effector from specified values for the joint parameters.

- trajectory planning:

robot manipulator trajectory planning takes the ideal trajectory kinematics parameters and the

robot manipulator system as the input, and takes the displacement, velocity and acceleration of

each joint and end effector as the output.


13 | P a g e

-Jacobian matrix:

Jacobian is the determinant of the Jacobian matrix. The matrix will contain all partial derivatives of a vector function. The main use of Jacobian is found in the transformation of coordinates. It deals with the concept of differentiation with coordinate transformation.


14 | P a g e
- The fabrication processes:

We use wooden laser cut to build the feeding mechanism and the stand which the robot will put the products in it.

And use the 3d printer to abdicate the robot arm.


15 | P a g e
- The electrical system and integration:
- The sequence of the project and algorithms

16 | P a g e
- Summary:

As soon as we connect the power, the robot performs a homing

and returns to the initial position. After that, the feeding

mechanism performs a homing and returns to the initial position.

After that, the laptop takes pictures of each part separately to

move to the next time once the products are captured correctly

and the word “Done” is displayed, then after. The laptop then

gives a sequence of the location of each product, so the robot

collects similar products on this basis, assembles them, and then

transports them to their storage location.

We use two microprocessors (Arduino uno - laptop) , the two

microprocessors connecting with to each other with UART

protocol via USB.


17 | P a g e
- Flow chart:


18 | P a g e
- the schematic electrical circuit:

19 | P a g e
- The PID controller on DC motor in feeding:

We Utilize sensors like encoders to measure the motor's current position, providing feedback for the control system.

1. Proportional (P) Control: Adjust motor speed based on the difference between desired and current position, increasing or decreasing power accordingly to move closer to the setpoint.
2. Integral (I) Control: Accumulate errors over time to eliminate steady-state error, correcting for any system bias preventing the motor from reaching the desired position.
4. Derivative (D) Control: Anticipate changes in error rate to dampen overshoot and oscillations, adjusting power based on the rate of change of error.
5. Tuning Parameters: Crucially adjust PID parameters to balance responsiveness, stability, and accuracy, typically starting with proportional gain and incrementally adding integral and derivative terms while observing system response.
6. Continuous Adjustment: Once tuned, the PID controller continuously computes a control signal based on the error, ensuring the motor reaches and maintains the desired position accurately and efficiently.

In essence, PID control offers a versatile and effective method for precise position control of DC motors, crucial for various applications like robotics and automation systems.
In our case We chose it due to previous experiences with PID values for same motor and modified it with our case.
| Kp | Ki | Kd
Value | 5.2 | 0.001 | 1.0


20 | P a g e

Pode blot between desired and set point:

➢ The final product and problems faced:; • problems faced:; caught by the robot.; quality of the motor.; Final product

1- | the small error on PID controller and This causes the product not to be
| We made a great effort to avoid this error by controlling and changing PID parameters, but we were not able to remove it due to the poor

22 | P a g e
2- | The machine vision camera is affected by external factors such as light, so it must be adjusted before conducting the experiment.
3- | The problems of MATLAB program as error, we can’t solve it.
4- | The gripper when its puck up the products, we solve it by change motor with high torque to overcome the friction between links and bolts and nuts.
5- | Modifying the CNC shield to can use one Arduino, That modification is to remove the Step-X motor pin 2 and connect it to the pin 0, so that we can use the pin 2 with interrupt with DC encoders.

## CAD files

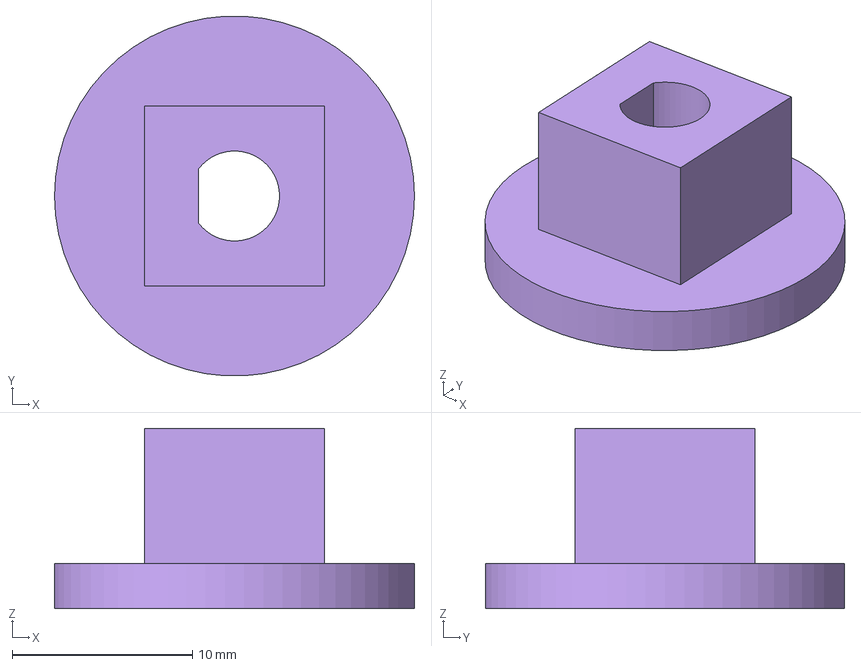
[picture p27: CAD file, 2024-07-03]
Mechatronics System Desigen/Feeding_mechanical_design/feeding_coupler_Nema17.stp
20.0 x 20.0 x 10.0 mm

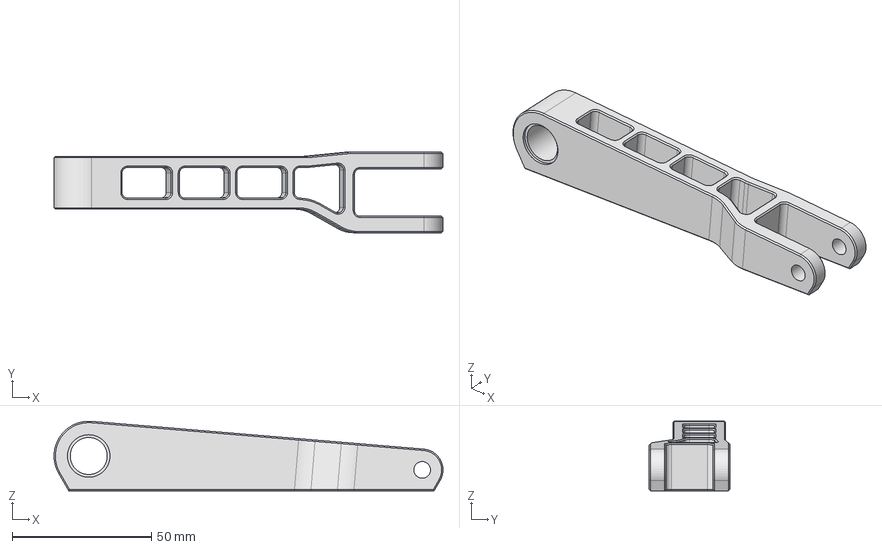
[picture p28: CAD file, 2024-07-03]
Mechatronics System Desigen/Robot_Arm_simulation_on_Matlab/ForwardKinematics/lowerShank_ipt_62d74757.STEP
139.9 x 29.0 x 25.0 mm

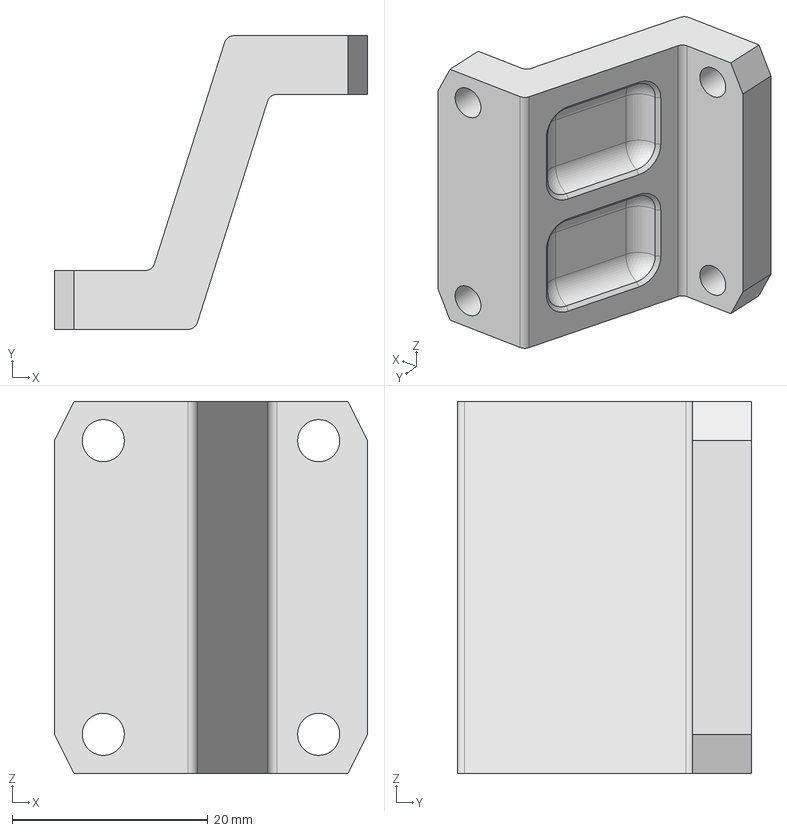
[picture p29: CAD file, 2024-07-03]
Mechatronics System Desigen/Robot_Arm_simulation_on_Matlab/Jacobian/leg_30mm_ipt_3d66126c.STEP
32.0 x 30.0 x 38.0 mm

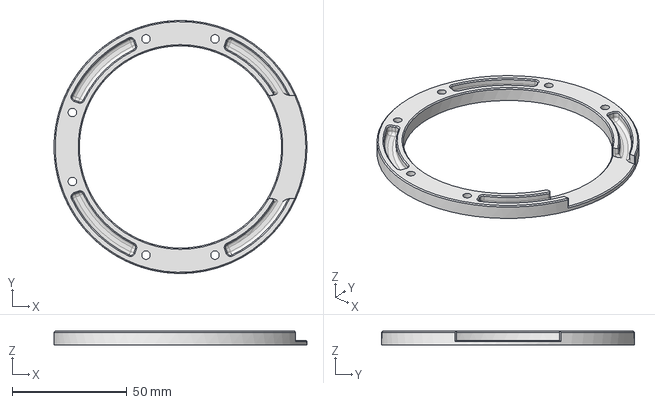
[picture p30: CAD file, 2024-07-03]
Mechatronics System Desigen/Robot_Arm_simulation_on_Matlab/trajectory/baseRing_ipt_49794671.STEP
110.0 x 110.0 x 6.00 mm

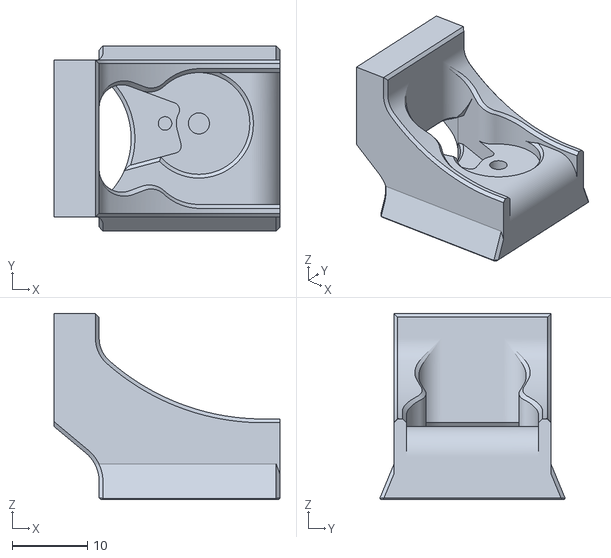
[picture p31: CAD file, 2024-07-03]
Mechatronics System Desigen/RobotArm_mechanical_design/files/gripperFinger.stl
30.0 x 24.6 x 24.7

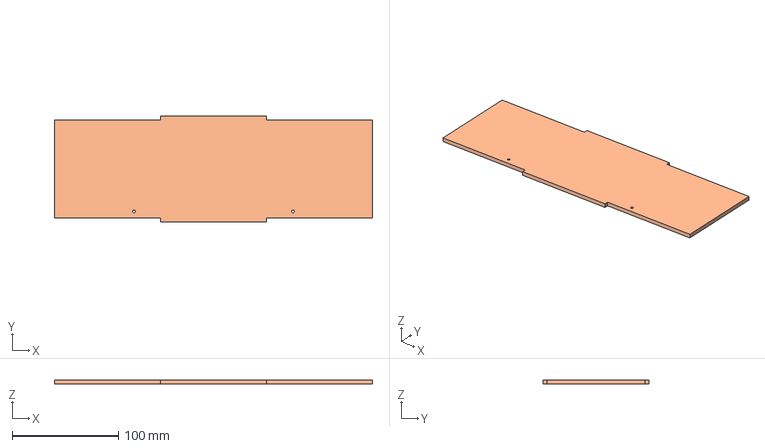
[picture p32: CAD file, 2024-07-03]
Mechatronics System Desigen/Feeding_mechanical_design/feeding_side.stp
300.0 x 100.0 x 4.00 mm

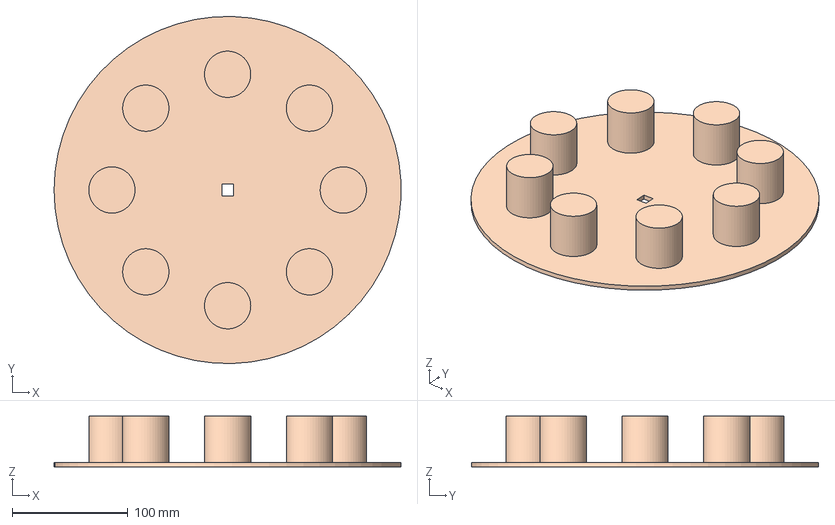
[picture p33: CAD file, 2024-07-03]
Mechatronics System Desigen/Robot_Arm_simulation_on_Matlab/feeding_matlab/feeding_rotating_plate_ipt_d2814483.STEP
299.8 x 299.9 x 44.0 mm

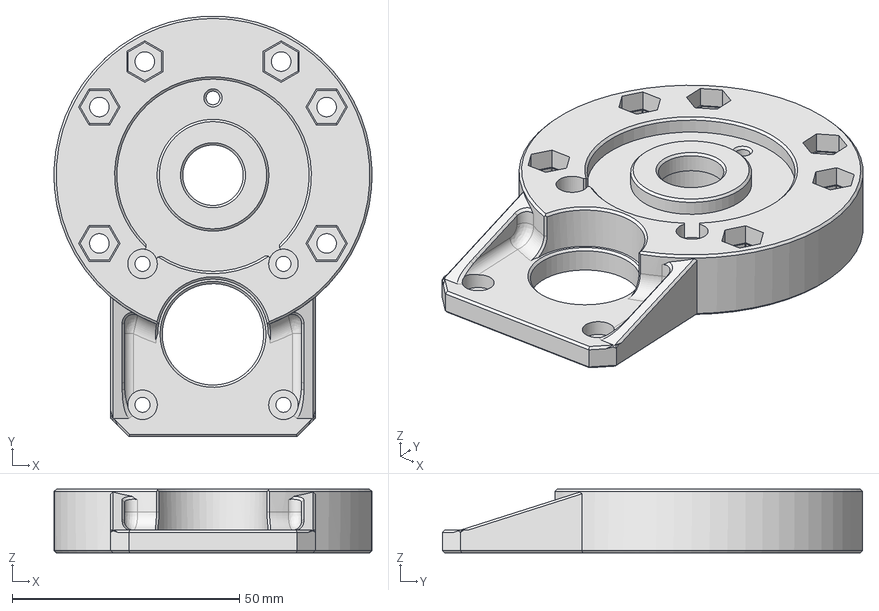
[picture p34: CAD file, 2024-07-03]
Mechatronics System Desigen/Robot_Arm_simulation_on_Matlab/InversKinematics/socket_ipt_3493b8b2.STEP
70.0 x 92.4 x 14.0 mm

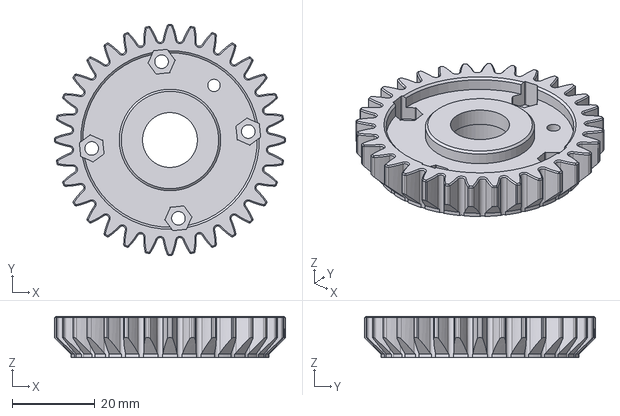
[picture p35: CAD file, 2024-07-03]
Mechatronics System Desigen/Robot_Arm_simulation_on_Matlab/Jacobian/GearRotate_0.20mmTolerance_ipt_1ca153fe.STEP
56.0 x 56.0 x 10.0 mm

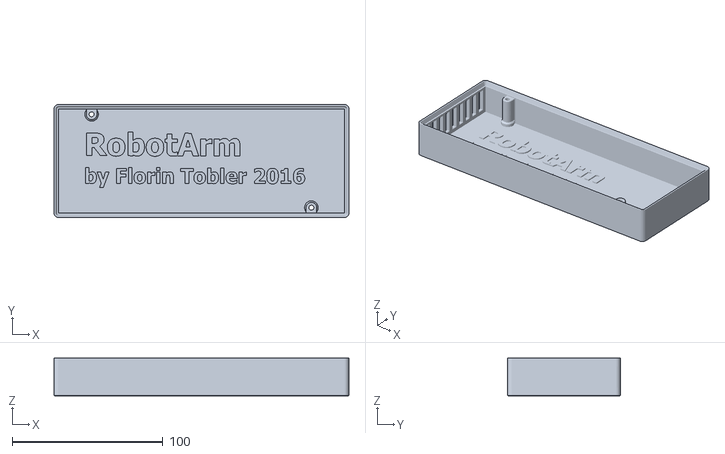
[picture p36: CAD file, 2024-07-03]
Mechatronics System Desigen/RobotArm_mechanical_design/files/control_top.stl
196.0 x 75.0 x 25.0

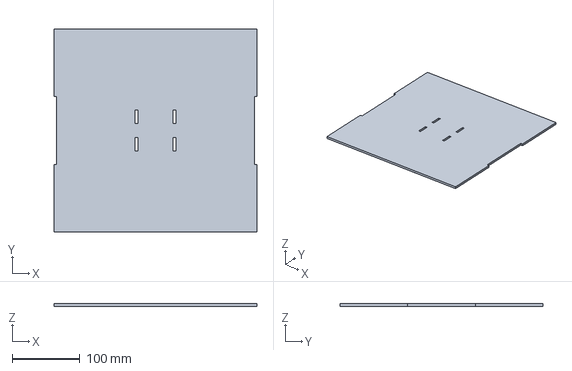
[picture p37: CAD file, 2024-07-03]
Mechatronics System Desigen/Feeding_mechanical_design/feeding_base.stp
300.0 x 300.0 x 4.00 mm

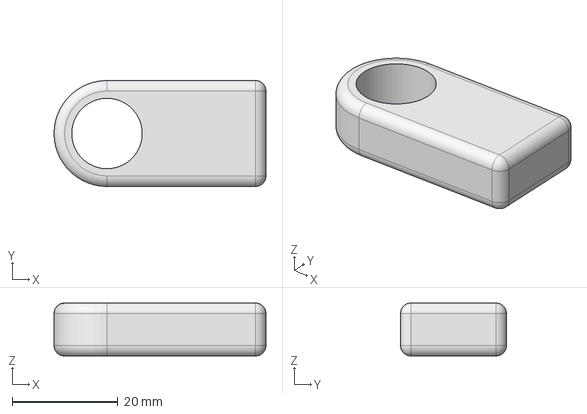
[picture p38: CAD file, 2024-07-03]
Mechatronics System Desigen/Robot_Arm_simulation_on_Matlab/ForwardKinematics/Part1_ipt_4b03ec28.STEP
40.0 x 20.0 x 10.0 mm

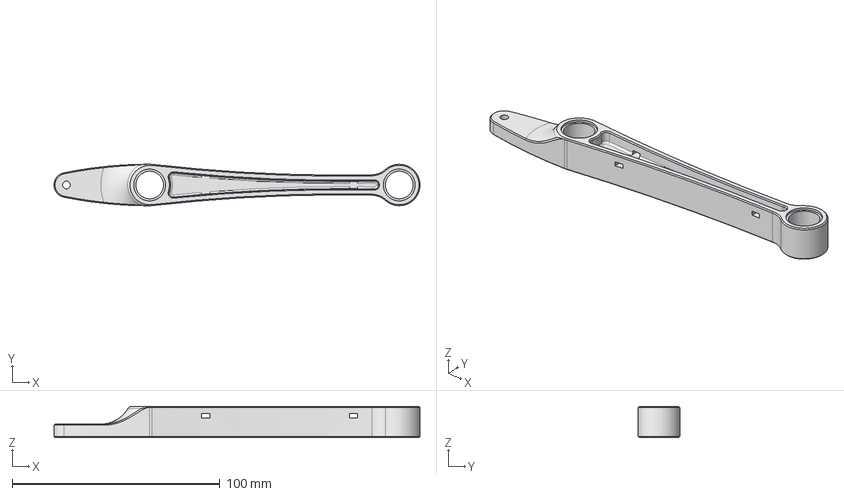
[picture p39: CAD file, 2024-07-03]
Mechatronics System Desigen/Robot_Arm_simulation_on_Matlab/InversKinematics/upperShank_ipt_e487e912.STEP
176.0 x 20.0 x 15.0 mm

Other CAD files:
Mechatronics System Desigen/Robot_Arm_simulation_on_Matlab/feeding_matlab/feeding_coupler_Nema17_ipt_860a6420.STEP
Mechatronics System Desigen/Robot_Arm_simulation_on_Matlab/feeding_matlab/feeding_parts_stand_ipt_1f4819e8.STEP
Mechatronics System Desigen/Feeding_mechanical_design/Assembly2.iam
Mechatronics System Desigen/Feeding_mechanical_design/OldVersions/Assembly2.0002.iam
Mechatronics System Desigen/Feeding_mechanical_design/OldVersions/feeding_rotating_plate.0001.ipt
Mechatronics System Desigen/Feeding_mechanical_design/feeding_coupler_Nema17.ipt
Mechatronics System Desigen/Feeding_mechanical_design/feeding_parts_stand.ipt
Mechatronics System Desigen/Feeding_mechanical_design/feeding_parts_stand.stp
Mechatronics System Desigen/Feeding_mechanical_design/feeding_rotating_plate.ipt
Mechatronics System Desigen/Feeding_mechanical_design/feeding_rotating_plate.stp
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

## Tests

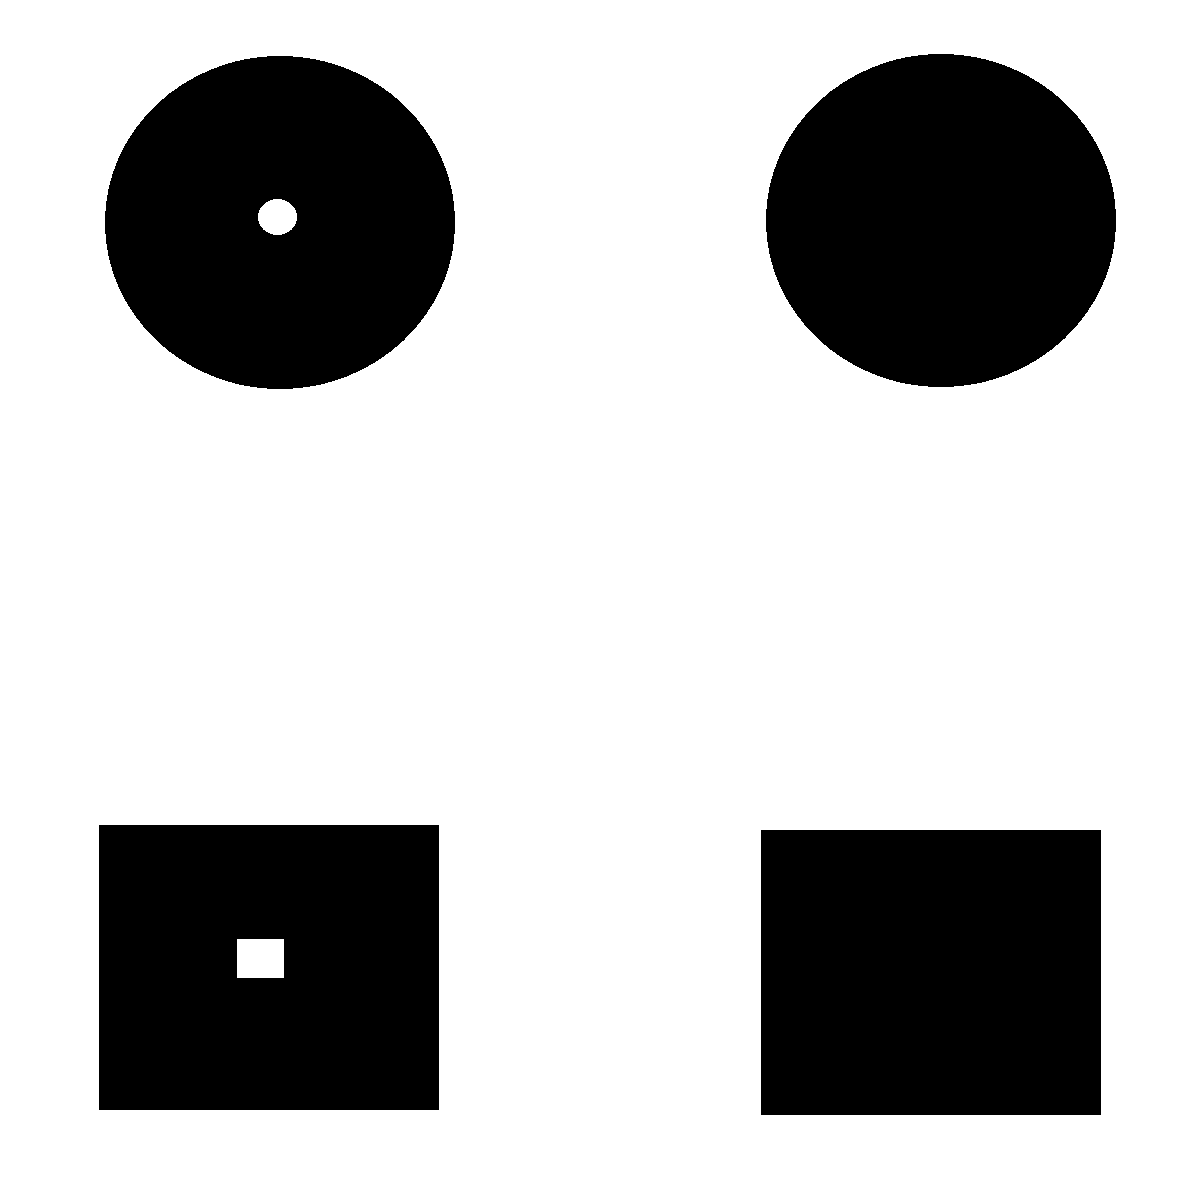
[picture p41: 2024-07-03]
Mechatronics System Desigen/Code/pythonProject/TestImg/4objects.png

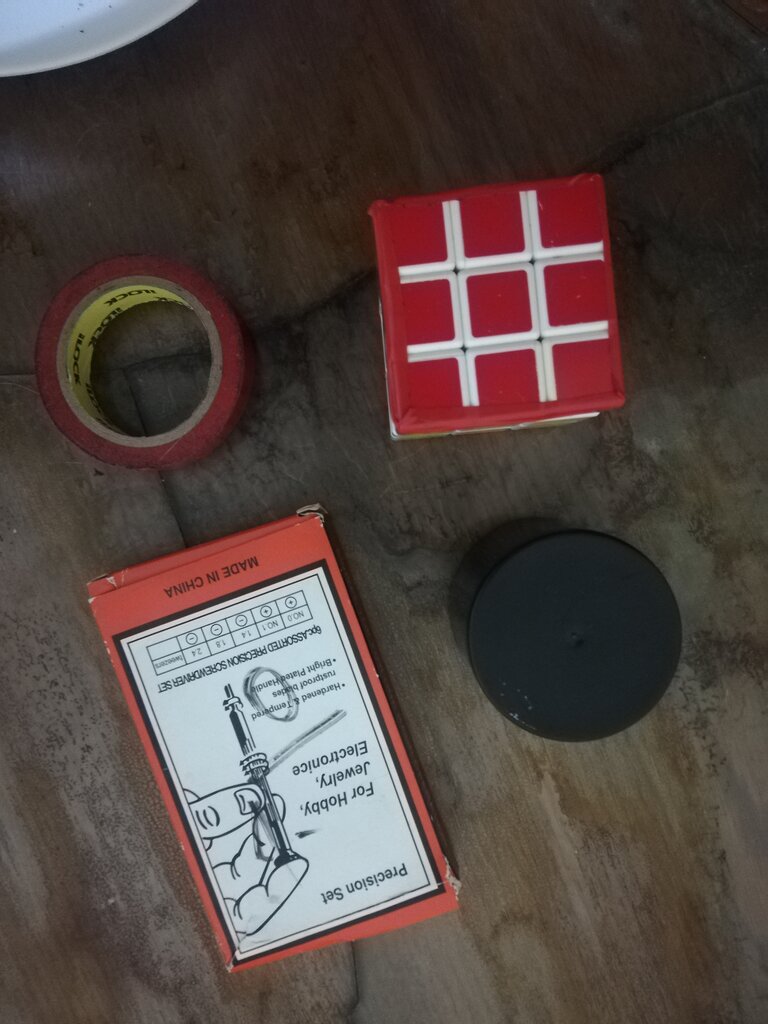
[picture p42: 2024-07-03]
Mechatronics System Desigen/Code/pythonProject/TestImg/objects5 (1).jpg

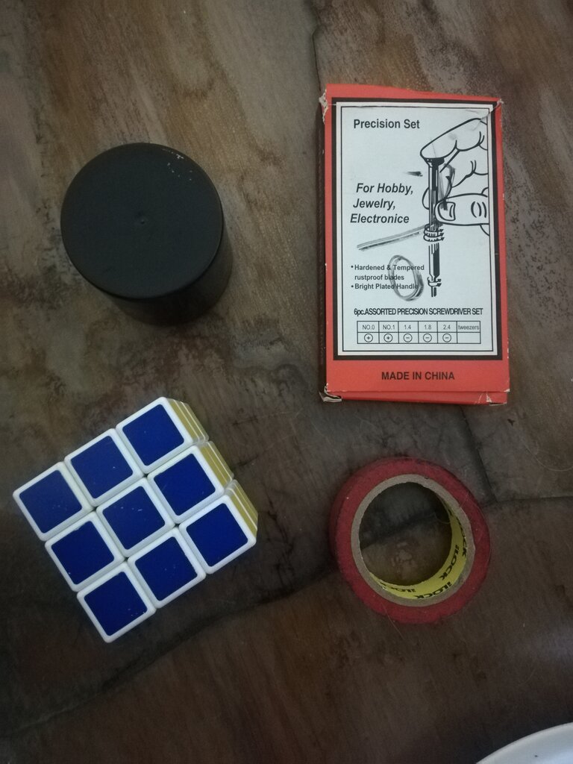
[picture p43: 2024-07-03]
Mechatronics System Desigen/Code/pythonProject/TestImg/objects4 (1).jpg

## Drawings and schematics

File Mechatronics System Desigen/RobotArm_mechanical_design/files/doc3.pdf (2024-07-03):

# RobotArm

# Ingrediences

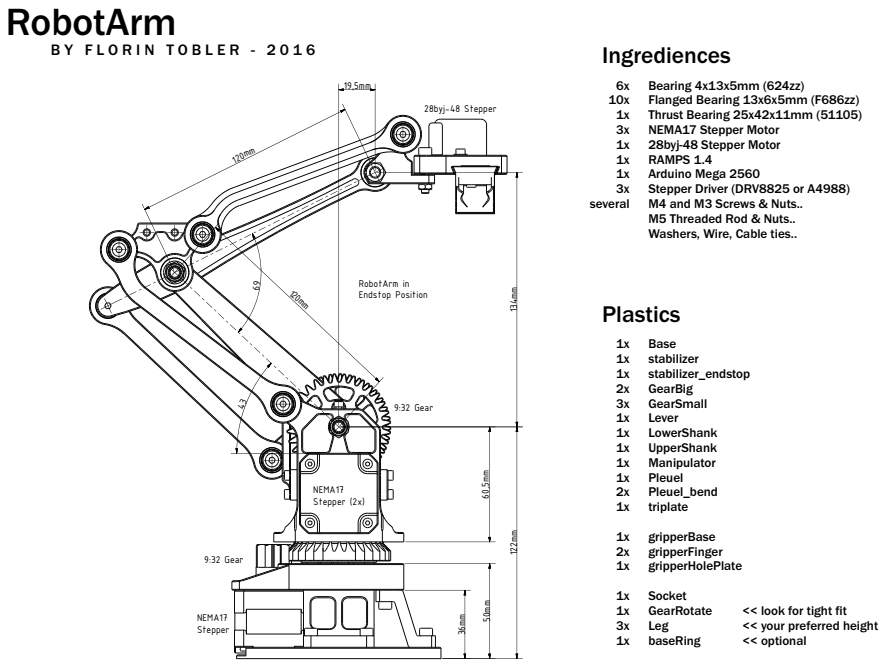
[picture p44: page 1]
Plastics; 6x 10x 1x 3x 1x 1x 1x 3x several; Bearing 4x13x5mm (624zz) Flanged Bearing 13x6x5mm (F686zz) Thrust Bearing 25x42x11mm (51105) NEMA17 Stepper Motor 28byj-48 Stepper Motor RAMPS 1.4 Arduino Mega 2560 Stepper Driver (DRV8825 or A4988) M4 and M3 Screws & Nuts.. M5 Threaded Rod & Nuts.. Washers, Wire, Cable ties..; Base stabilizer stabilizer_endstop GearBig GearSmall Lever LowerShank UpperShank Manipulator Pleuel Pleuel_bend triplate; gripperBase gripperFinger gripperHolePlate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

<< look for tight fit
<< your preferred height
<< optional

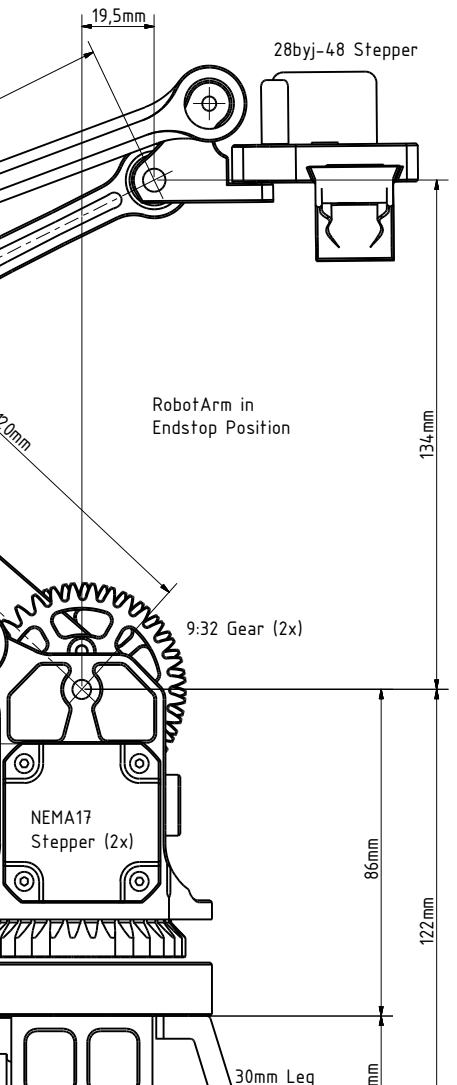
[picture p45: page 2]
9:32 Gear (2x); NEMA17 Stepper (2x); RobotArm in Endstop Position; 28byj-48 Stepper; Stepper; 30mm Leg

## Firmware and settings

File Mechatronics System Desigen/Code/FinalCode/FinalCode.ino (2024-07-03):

#include <AccelStepper.h>
#include <Servo.h>
#include <cvzone.h>
// Define the stepper motor and the pins that is connected to
AccelStepper StepperX(1, A5, 5); // (Type of driver: with 2 pins, STEP, DIR)
AccelStepper StepperY(1, 3, 6);
AccelStepper StepperZ(1, 4, 7);
Servo Gripper;
#define LimitX 9
#define LimitY 10
#define LimitZ A2
#define  outputencA 2 //yellow  
#define outputencB A1 //green
#define LimitF A0
#define  input1 12
#define  input2 13
#define   PWM   11
#define button A4
SerialData serialData(1,1);
SerialData sequenceData(22,1);
int signalout[2];
int signalin[1];
int sequence[22];
int postion =0;
float angle=0;
float increment = (360.0/512.0);
long time1=0;
float kp =5.2;
float kd =1.0;
float ki =0.001;
long previoustime =0;
float eprevious =0 ;
float eintegral =0;
int targ = 45;
const int maxspeed = 400;
const int accel = 400;
const float ratio = (800/101.25);
int grip = 1;
int HomeX = 0;
int HomeY = 0;
int HomeZ = 0;
int assembly=0;
int storagesquare=0;
int storagecircle=0;

void setup() {
  pinMode(A4,INPUT_PULLUP);
  pinMode(LimitX,INPUT_PULLUP);
  pinMode(LimitY,INPUT_PULLUP);
  pinMode(LimitZ,INPUT_PULLUP);
  StepperX.setMaxSpeed(maxspeed);
  StepperX.setAcceleration(accel);
  StepperX.setCurrentPosition(0);
  StepperY.setMaxSpeed(maxspeed);
  StepperY.setAcceleration(accel);
  StepperY.setCurrentPosition(0);
  StepperZ.setMaxSpeed(maxspeed);
  StepperZ.setAcceleration(accel);
  StepperZ.setCurrentPosition(0);
  Gripper.attach(A3);
  Gripper.write(grip);
  
  pinMode(outputencA,INPUT);
  pinMode(outputencB,INPUT);
  pinMode(input1,OUTPUT);
  pinMode(input2,OUTPUT);
  pinMode(PWM,OUTPUT);
  pinMode(LimitF,INPUT_PULLUP);
  attachInterrupt(digitalPinToInterrupt(outputencA),readEncoder,RISING);
  delay(3000);
  Home();
  HomeF();
  serialData.begin();
}

void loop() {
  if(digitalRead(button)==0){
  time1=micros();
  vision();
  delay(3000);
  time1=micros();
  AvengersAssemble();
}
   }


void AvengersAssemble(){
  int index=2;
  if(sequence[index]==0 && sequence[index+1]==0){
    base();
    assembly++;
    index+=2;
  }
  while(index<22){
    if(index==6 || index==11 || index==16 || index==21){
      if(sequence[index]==7){
        storesquare();
        index++;
        continue;
      }
      else if(sequence[index]==8){
        storecircle();
        index++;
        continue;
      }
    }
    if(sequence[index+1]==5){
      targ+=sequence[index]*45;
    }
    else if(sequence[index+1]==6){
      targ-=sequence[index]*45;
    }
    TurnFeed(targ);
    if(assembly%2==0){
      base();
      assembly++;
      index+=2;
    }
    else if(assembly%2==1){
      lid();
      assembly++;
      index+=2;
    }
  }
  if(storagesquare==2 && storagecircle==2){
    while(1){}
  }
}

void base(){
  Actuate(-23,2,0);
  Grip();
  Actuate(20,-15,0);
  Actuate(20,-15,-61);
  Actuate(-24,4,-61);
  UnGrip();
  Actuate(20,-15,-61);
  Actuate(20,-15,0);
}

void lid(){
  Actuate(-23,2,0);
  Grip();
  Actuate(-10,-50,0);
  Actuate(-10,-50,-61);
  Actuate(-5,-20,-61);
  UnGrip();
}

void storesquare(){
  if(storagesquare==1){
  Actuate(-23,-2,-61);
  Grip();
  Actuate(5,-66,-61);
  Actuate(5,-66,-104);
  Actuate(-19,0,-104);
  UnGrip();
  Actuate(5,-66,-104);
  Actuate(5,-66,0);
  Actuate(0,0,0);
  storagesquare++;
  }
  else if(storagesquare==0){
  Actuate(-23,-2,-61);
  Grip();
  Actuate(5,-66,-61);
  Actuate(5,-66,-134);
  Actuate(-19,0,-134);
  UnGrip();
  Actuate(5,-66,-134);
  Actuate(5,-66,0);
  Actuate(0,0,0);
  storagesquare++;
  }
}

void storecircle(){
  if(storagecircle==0){
  Actuate(-23,-2,-61);
  Grip();
  Actuate(5,-66,-61);
  Actuate(5,-66,-214);
  Actuate(-19,0,-214);
  UnGrip();
  Actuate(5,-66,-214);
  Actuate(5,-66,0);
  Actuate(0,0,0);
  storagecircle++;
  }
  else if(storagecircle==1){
  Actuate(-23,-2,-61);
  Grip();
  Actuate(5,-66,-61);
  Actuate(5,-66,-184);
  Actuate(-19,0,-184);
  UnGrip();
  Actuate(5,-66,-184);
  Actuate(5,-66,0);
  Actuate(0,0,0);
  storagecircle++;
  }
}

void Home(){
  StepperX.setSpeed(200);
  StepperY.setSpeed(-300);
  StepperZ.setSpeed(300);
  while(1){
  if(digitalRead(LimitX)==0){
    HomeX = 1;
  }
  if(digitalRead(LimitY)==0){
    HomeY = 1;
  }
  if(digitalRead(LimitZ)==0){
    HomeZ = 1;
  }
  if (HomeX==0){
    StepperX.runSpeed();
  }
  else if (HomeX==1){
    StepperX.stop();
  }
  if (HomeY==0){
    StepperY.runSpeed();
  }
  else if (HomeY==1){
    StepperY.stop();
  }
  if (HomeZ==0 && HomeX==1 && HomeY==1){
    StepperZ.runSpeed();
  }
  else if (HomeZ==1){
    StepperZ.stop();
  }
  if(HomeX==1 && HomeY==1 && HomeZ==1){
    break;
  }
  }
  StepperX.setCurrentPosition(0);
  StepperY.setCurrentPosition(0);
  StepperZ.setCurrentPosition(0);
  StepperX.moveTo(-ceil(40*ratio));
  StepperY.moveTo(ceil(67*ratio));
  StepperZ.moveTo(-ceil(2*ratio));
  while(StepperX.currentPosition()!=-ceil(40*ratio) || StepperY.currentPosition()!=ceil(67*ratio) || StepperZ.currentPosition()!=-ceil(2*ratio)){
    StepperX.run();
    StepperY.run();
    StepperZ.run();
  }
  StepperX.setCurrentPosition(0);
  StepperY.setCurrentPosition(0);
  StepperZ.setCurrentPosition(0);
}

void Actuate(int xangle, int yangle, int zangle){
  int x;
  int y;
  int z;
  if(xangle>=0){
    x=ceil(xangle*ratio);
    StepperX.moveTo(x);
  }
  else{
    x=-ceil(abs(xangle*ratio));
    StepperX.moveTo(x);
  }
  if(yangle>=0){
    y=ceil(yangle*ratio);
    StepperY.moveTo(y);
  }
  else{
    y=-ceil(abs(yangle*ratio));
    StepperY.moveTo(y);
  }
  if(zangle>=0){
    z=ceil(zangle*ratio);
    StepperZ.moveTo(z);
  }
  else{
    z=-ceil(abs(zangle*ratio));
    StepperZ.moveTo(z);
  }
  while(StepperX.currentPosition()!=x || StepperY.currentPosition()!=y || StepperZ.currentPosition()!=z){
    StepperX.run();
    StepperY.run();
    StepperZ.run();
  }
}

void ActuateRelative(int xangle, int yangle, int zangle){
  int x;
  int y;
  int z;
  if(xangle>=0){
    x=ceil(xangle*ratio);
    StepperX.move(x);
  }
  else{
    x=-ceil(abs(xangle*ratio));
    StepperX.move(x);
  }
  if(yangle>=0){
    y=ceil(yangle*ratio);
    StepperY.move(y);
  }
  else{
    y=-ceil(abs(yangle*ratio));
    StepperY.move(y);
  }
  if(zangle>=0){
    z=ceil(zangle*ratio);
    StepperZ.move(z);
  }
  else{
    z=-ceil(abs(zangle*ratio));
    StepperZ.move(z);
  }
  while(StepperX.currentPosition()!=x || StepperY.currentPosition()!=y || StepperZ.currentPosition()!=z){
    StepperX.run();
    StepperY.run();
    StepperZ.run();
  }
}

void Grip(){
    Gripper.write(40);
}

void UnGrip(){
    Gripper.write(1);                       
  }

void readEncoder(){
  int b =digitalRead(outputencB);
  if(b>0){
    postion++;
    angle+=increment;
  }
  else {
    postion--;
    angle-=increment;
  }
  
}

void movemotor (int dir , int pwmvalue, int pwm ,int in1 ,int in2 ){
  analogWrite(pwm,pwmvalue);
  if(dir == 1)
  {
  digitalWrite(in1,HIGH);
  digitalWrite(in2,LOW);
  }
 else if (dir == -1)
 {
  digitalWrite(in1,LOW);
  digitalWrite(in2,HIGH);
 }
 else if ( dir ==0) 
 {
  digitalWrite(in1,LOW);
  digitalWrite(in2,LOW);
 }

}

float pidcontrol (int target ,float kp,float kd,float ki){
  float u;
  //get delta t
  long currenttime = micros()-time1;
  float deltaT =((float)(abs(currenttime-previoustime))) /1.0e6;
  
  //calculate error ,derivative ,integral
  float e = angle -target ;

  if(fabs(e)<increment)
  {
    return 0;
  }
  float edrivative =(e-eprevious)/ deltaT ;
  eintegral = eintegral + e * deltaT ;
  
  // contrpal signal
  u = (kp * e) + (kd * edrivative) +( ki * eintegral);
  //update variable for next iteration
  previoustime =  currenttime ;
  eprevious =e ;
  return u ;
}

void HomeF(){
  int pwr=45;
  int dir=-1;
  while(1){
  movemotor(dir,pwr,PWM,input1,input2);
  if(digitalRead(LimitF)==0){
    int fix=0;
    while(fix<30){
    pwr=49;
    dir=1;
    movemotor(dir,pwr,PWM,input1,input2);
    delay(45);
    pwr=0;
    dir=0;
    movemotor(dir,pwr,PWM,input1,input2);
    delay(55);
    fix++;
    }
    movemotor(0,0,PWM,input1,input2);
    break;
  }
  }
    postion=0;
    angle=0;
    return;
}

void TurnFeed(int target){  
    float u = 1;//pid variable
    eintegral=0;
    while(u!=0 ){
    u = pidcontrol (target ,kp ,kd,ki);

 //motor power
    float pwr =fabs(u);
    if(pwr>235)
    {
      pwr=235;
    }
    else if(pwr<55)
    {
      pwr=55;
    }
    
 //motor direction
  int dir =1 ;
  if (u==0)
  {
    dir=0 ;
  }  
  else if (u<0)
  {
    dir=-1 ;
  }


  movemotor (dir,pwr,PWM,input1,input2);

    delay(25);
   }
   return;
}

void vision(){
  signalout[0]=9;
  serialData.Send(signalout);
  int counter=0;
  signalout[0]=8;
  while(counter<7)
    {
    while(1)
    {
      serialData.Get(signalin);
      if(signalin[0]==1+counter)
      {
        signalin[0]=0;
        break;
      }
    }
    TurnFeed(targ);
    delay(50);
    signalout[0]=8-counter;
    serialData.Send(signalout);
    counter++;
    targ+=45;
    }
    targ-=45;
    signalout[0]=8-counter;
    serialData.Send(signalout);
    delay(100);
    int h=0;
    while(h<2500){
      serialData.Get(signalin);
      delay(1);
      h++;
    }
    while(sequence[21]==0)
    {
    sequenceData.Get(sequence);
    }
    /*delay(1000);
    Serial.flush();
    int l=0;
    while(l<sizeof(sequence)){
    signalout[0]=sequence[l];
    serialData.Send(signalout);
    l++;
    delay(1000);
    }*/
    Serial.end();
}

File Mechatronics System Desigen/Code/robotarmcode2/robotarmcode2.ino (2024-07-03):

#include <cvzone.h>

SerialData serialData(1,1);
SerialData sequenceData(20,1);
int signalout[2];
int signalin[1];
int sequence[20];

void setup() {
serialData.begin();
pinMode(13,INPUT_PULLUP);
}

void loop() {
if (digitalRead(13)==0)
{
  signalout[0]=9;
  serialData.Send(signalout);
  int counter=0;
  int position=1;
  signalout[0]=8;
  while(counter<7)
    {
    while(1)
    {
      serialData.Get(signalin);
      if(signalin[0]==1+counter)
      {
        signalin[0]=0;
        break;
      }
    }
    delay(2500);
    signalout[0]=8-counter;
    serialData.Send(signalout);
    position++;
    counter++;
    }
    signalout[0]=8-counter;
    serialData.Send(signalout);
    delay(100);
    int h=0;
    while(h<2000){
      serialData.Get(signalin);
      delay(1);
      h++;
    }
    while(sequence[19]==0)
    {
    sequenceData.Get(sequence);
    }
    delay(1000);
    int l=0;
    while(l<sizeof(sequence)){
    signalout[0]=sequence[l];
    serialData.Send(signalout);
    l++;
    delay(1000);
    }
    Serial.end();
}
}
